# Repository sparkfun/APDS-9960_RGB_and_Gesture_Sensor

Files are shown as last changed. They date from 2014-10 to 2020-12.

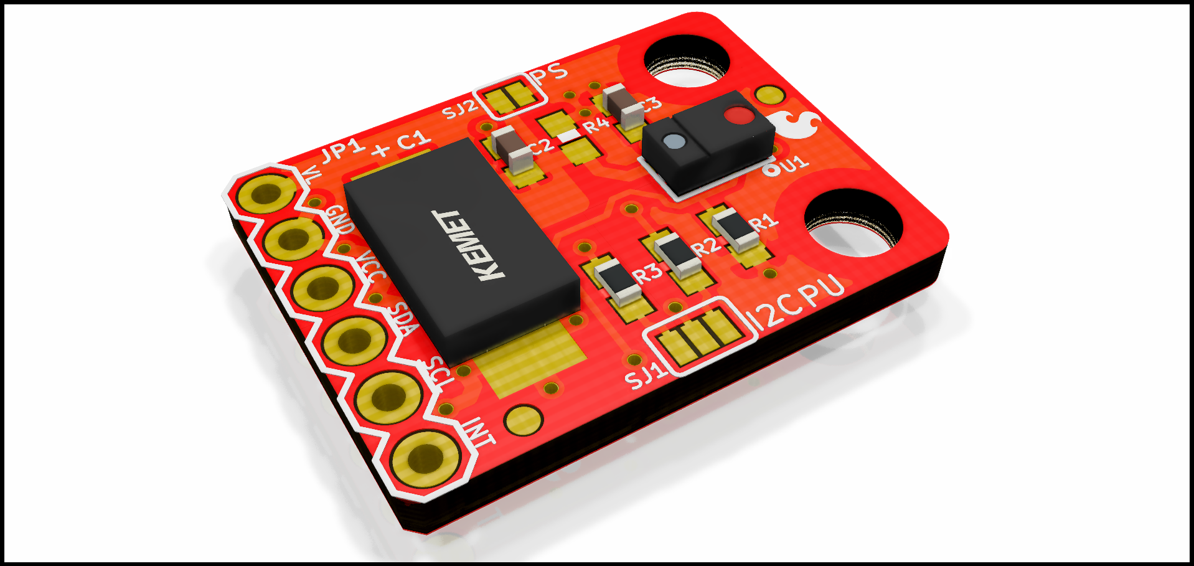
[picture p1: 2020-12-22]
Hardware/Kicad/RENDERS/SparkFun_APDS-9960_RGB_and_Gesture_Sensor_05.png

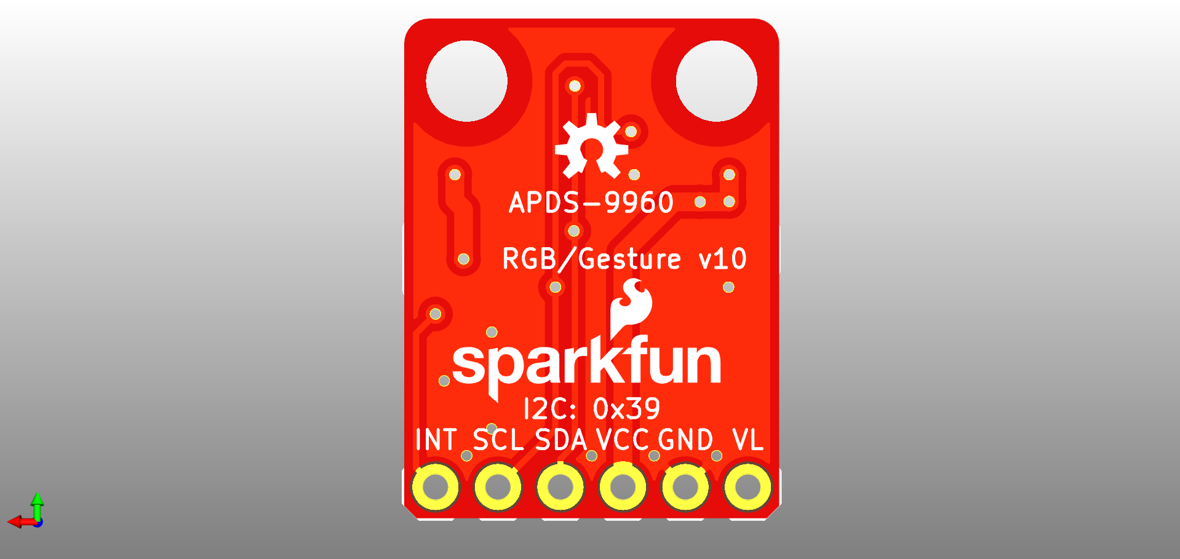
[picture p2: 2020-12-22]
Hardware/Kicad/RENDERS/SparkFun_APDS-9960_RGB_and_Gesture_Sensor_02.png

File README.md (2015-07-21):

SparkFun APDS-9960 RGB and Gesture Sensor
========================================

SparkFun APDS-9960 RGB and Gesture Sensor Breakout

[*SparkFun APDS-9960 Breakout Board (SEN-12787)*](https://www.sparkfun.com/products/12787)

This is the SparkFun RGB and Gesture Sensor, a small breakout board with a built in APDS-9960 sensor that offers ambient light and color measuring, proximity detection, and touchless gesture sensing.
With this RGB and Gesture Sensor you will be able to control a computer, microcontroller, robot, and more with a simple swipe of your hand! 

 Repository Contents
-------------------

* **/Hardware** - Eagle design files (.brd, .sch)
* **/Libraries** - Libraries for use with the SparkFun APDS9960 RGB and Gesture Sensor
* **/Production** - Production panel files (.brd)

Documentation
--------------
* **[Quickstart Guide](https://learn.sparkfun.com/tutorials/apds-9960-rgb-and-gesture-sensor-hookup-guide)** - Basic hookup guide for the sensor.
* **[Library/README](https://github.com/sparkfun/SparkFun_APDS-9960_Sensor_Arduino_Library/tree/V_1.4.1)** - Arduino library for the SparkFun_APDS9960 RGB and Gesture Sensor.
* **[SparkFun Fritzing repo](https://github.com/sparkfun/Fritzing_Parts)** - Fritzing diagrams for SparkFun products.
* **[SparkFun 3D Model repo](https://github.com/sparkfun/3D_Models)** - 3D models of SparkFun products. 

Product Versions
----------------
* **[SEN-12787](https://www.sparkfun.com/products/12787)** - APDS-9960 RGB and Gesture Sensor

Version History
---------------
* [V_H1.0_L1.4.2](https://github.com/sparkfun/APDS-9960_RGB_and_Gesture_Sensor/tree/V_H1.0_L1.4.2) - Fixing library name compiliation error. 
* [V_H1.0_L1.4.1](https://github.com/sparkfun/APDS-9960_RGB_and_Gesture_Sensor/tree/V_H1.0_L1.4.1) - Fixing minor typos in both library and hardware files.
* [V_1.1.1](https://github.com/sparkfun/APDS-9960_RGB_and_Gesture_Sensor/tree/V_1.1.1) - Updated to new tag syntax
* [V11](https://github.com/sparkfun/APDS-9960_RGB_and_Gesture_Sensor/tree/v11) - Updated to new library structure
* [v10](https://github.com/sparkfun/APDS-9960_RGB_and_Gesture_Sensor/tree/v10) - Release
* [v01](https://github.com/sparkfun/APDS-9960_RGB_and_Gesture_Sensor/tree/v01)

License Information
-------------------
This product is _**open source**_! 

The **hardware** is released under [Creative Commons ShareAlike 4.0 International](https://creativecommons.org/licenses/by-sa/4.0/).

The **code** is beerware; if you see me (or any other SparkFun employee) at the local, and you've found our code helpful, please buy us a round!

Please use, reuse, and modify these files as you see fit. Please maintain attribution to SparkFun Electronics and release anything derivative under the same license.

Distributed as-is; no warranty is given.

- Your friends at SparkFun.

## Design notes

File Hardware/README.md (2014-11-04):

# What Are these Files?

The .sch and .brd files hare are Eagle CAD schematic and PCB design files.

These files were created with Eagle 6.5.0, you'll need Eagle 6.5 or later to open them up. There is a free, lite, version of Eagle available from [cadsoftusa.com](cadsoftusa.com).

# License

This product is open source! These Eagle files are released under the Creative Commons Share-Alike Attribution license ([CC BY-SA 3.0](http://creativecommons.org/licenses/by-sa/3.0/us/)).

Please use, reuse, and modify these files as you see fit. Please maintain attribution and release anything derivative under the same license.

- Your friends at SparkFun.

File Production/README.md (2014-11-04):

These are the production files SparkFun uses for printing PCBs, as well as the Eagle files for our test beds.

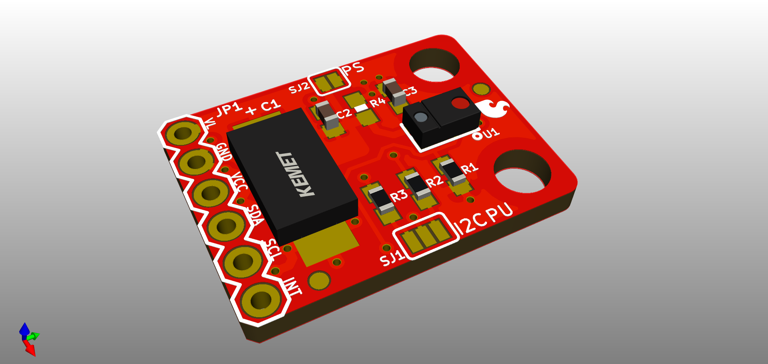
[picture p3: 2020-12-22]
Hardware/Kicad/RENDERS/SparkFun_APDS-9960_RGB_and_Gesture_Sensor_03.png

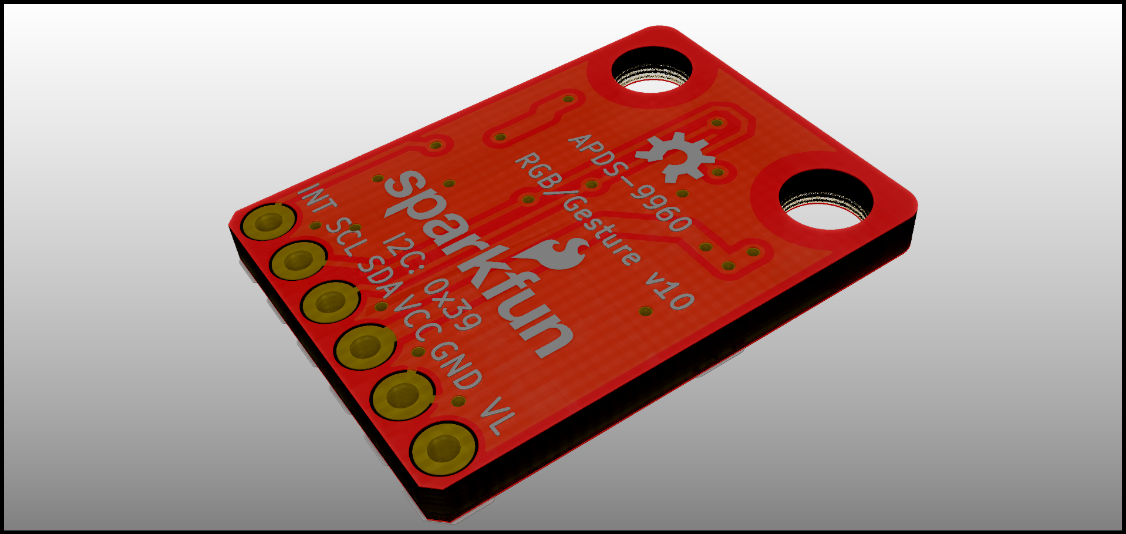
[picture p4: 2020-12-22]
Hardware/Kicad/RENDERS/SparkFun_APDS-9960_RGB_and_Gesture_Sensor_06.png

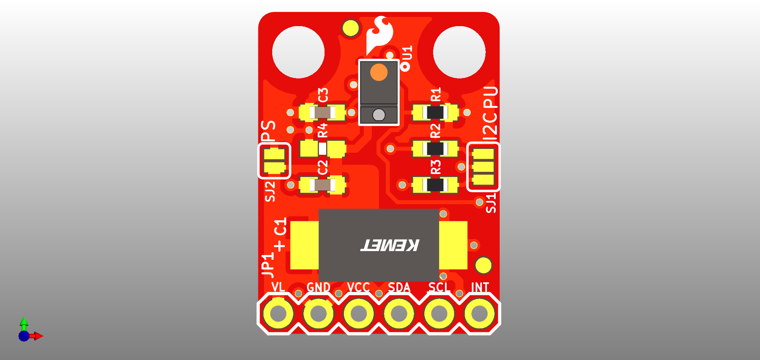
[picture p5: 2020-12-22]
Hardware/Kicad/RENDERS/SparkFun_APDS-9960_RGB_and_Gesture_Sensor_01.png

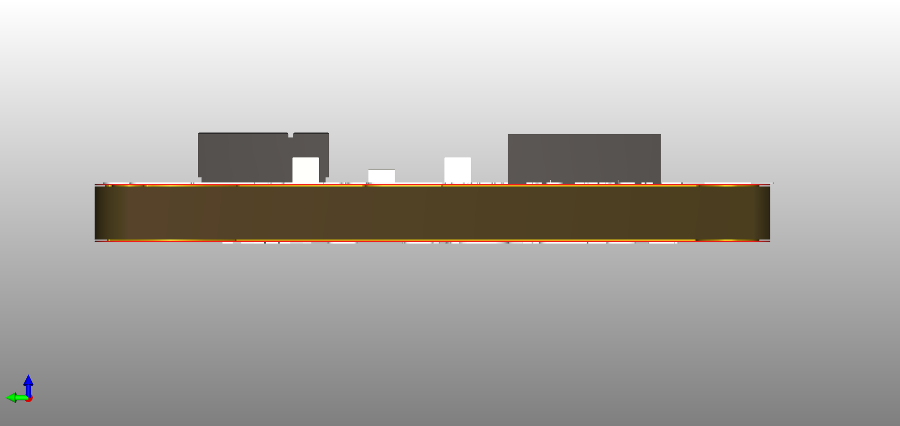
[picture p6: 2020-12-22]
Hardware/Kicad/RENDERS/SparkFun_APDS-9960_RGB_and_Gesture_Sensor_04.png

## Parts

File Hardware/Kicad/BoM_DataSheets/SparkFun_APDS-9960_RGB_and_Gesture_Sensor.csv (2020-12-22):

Id | Designator | Package | Quantity | Designation | Supplier and ref
1 | SJ2 | SJ_2S | 1 | SOLDERJUMPERNC
2 | U1 | APDS-9960 | 1 | APDS-9960
3 | C1 | c_2917 | 1 | 100uF
4 | C2,C3 | 0603-CAP | 2 | 1uF
5 | FID1,FID2 | FIDUCIAL-1X2 | 2 | FIDUCIAL1X2
6 | JP1 | 1X06 | 1 | M06SIP
7 | LOGO1 | SFE_LOGO_NAME_FLAME_.1 | 1 | SFE_LOGO_FLAME.1_INCH
8 | LOGO2 | OSHW-LOGO-S | 1 | OSHW-LOGOS
9 | R1 | 0603-RES | 1 | 10k
10 | R2,R3 | 0603 | 2 | 4.7k
11 | R4 | 0603-RES | 1 | DNP
12 | SJ1 | SJ_3_PASTE1&2&3 | 1 | SOLDERJUMPER_2WAYPASTE1&2&3
13 | STANDOFF1,STANDOFF2 | STAND-OFF | 2 | STAND-OFF
14 | U$1 | SFE_LOGO_FLAME_.1 | 1 | SFE_LOGO_NAME_FLAME.1_INCH

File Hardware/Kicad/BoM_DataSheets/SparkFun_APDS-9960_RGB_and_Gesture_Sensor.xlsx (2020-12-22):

Id | RefDes | Package | Quantity | Value
1 | C1 | c_2917 | 1 | 100uF
2 | C2, C3 | 0603-CAP | 2 | 1uF
3 | R1 | 0603-RES | 1 | 10k
4 | R2, R3 | 0603-CAP | 2 | 4.7k
5 | U1 | APDS-9960 | 1 | APDS-9960
 | KIT PARTS
6 | JP1 | 1X06 | 1 | M06SIP
 | DNP PARTS
7 | R4 | 0603-RES | 1 | DNP
 | VIRTUAL PARTS
8 | FID1, FID2 | FIDUCIAL-1X2 | 2 | FIDUCIAL1X2
9 | LOGO1 | SFE_LOGO_NAME_FLAME_.1 | 1 | SFE_LOGO_FLAME.1_INCH
10 | LOGO2 | OSHW-LOGO-S | 1 | OSHW-LOGOS
11 | SJ1 | SJ_3_PASTE1&2&3 | 1 | SOLDERJUMPER_2WAYPASTE1&2&3
12 | SJ2 | SJ_2S | 1 | SOLDERJUMPERNC
13 | STANDOFF1, STANDOFF2 | STAND-OFF | 2 | STAND-OFF
14 | U$1 | SFE_LOGO_FLAME_.1 | 1 | SFE_LOGO_NAME_FLAME.1_INCH

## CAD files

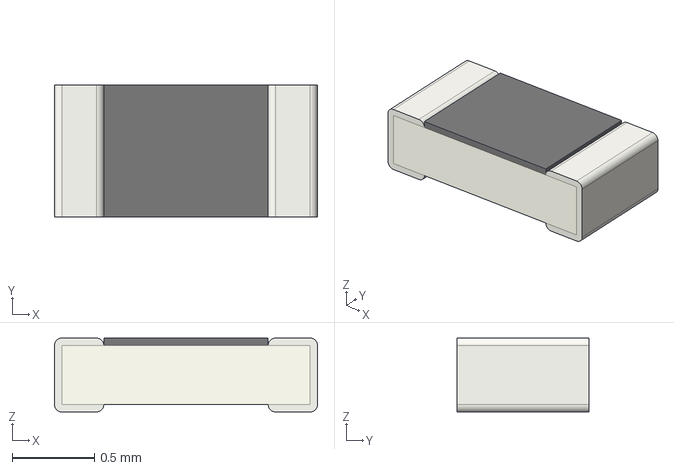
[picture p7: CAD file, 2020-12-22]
Hardware/Kicad/3D_models/R_0603_1608Metric.step
1.60 x 0.8 x 0.45 mm

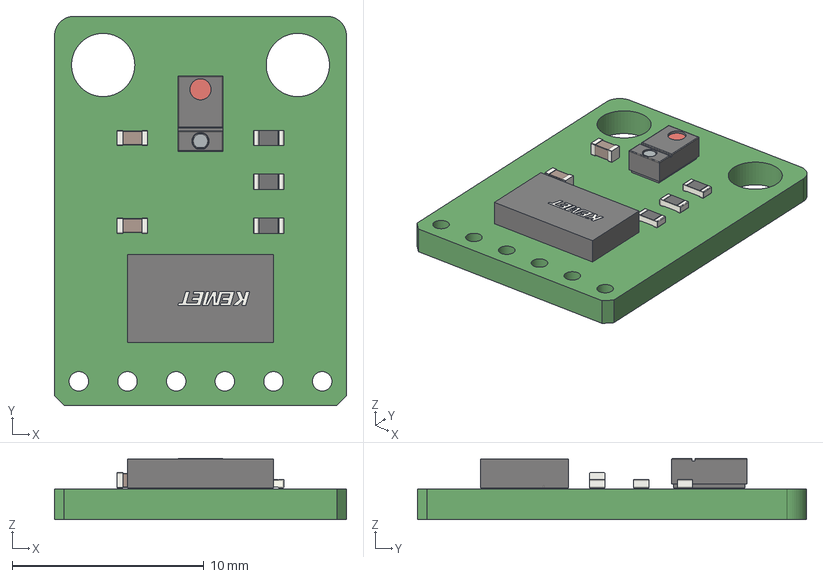
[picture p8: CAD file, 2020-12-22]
Hardware/Kicad/MECH/SparkFun_APDS-9960_RGB_and_Gesture_Sensor.step
15.2 x 20.3 x 3.20 mm

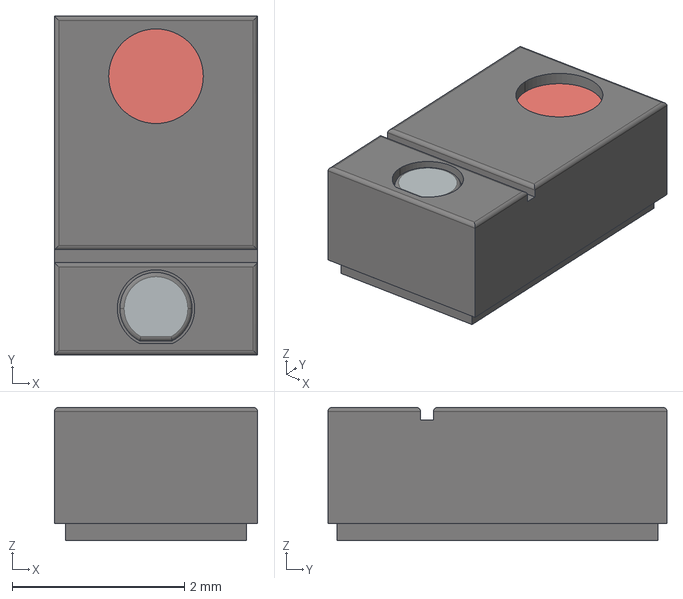
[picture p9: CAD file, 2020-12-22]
Hardware/Kicad/3D_models/APDS_9970_cp.step
2.36 x 3.94 x 1.55 mm

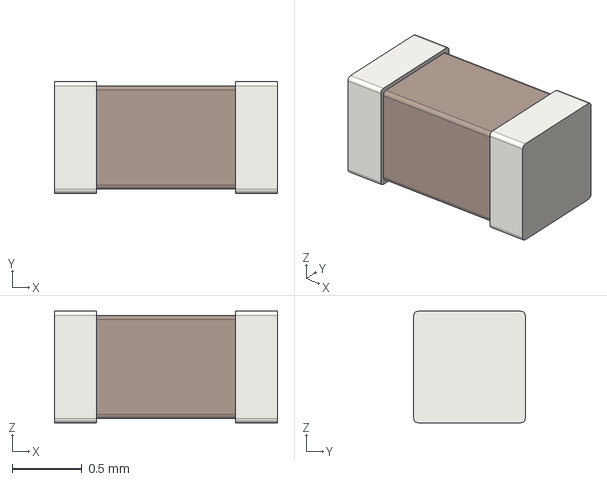
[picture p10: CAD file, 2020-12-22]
Hardware/Kicad/3D_models/C_0603_1608Metric.step
1.60 x 0.8 x 0.8 mm

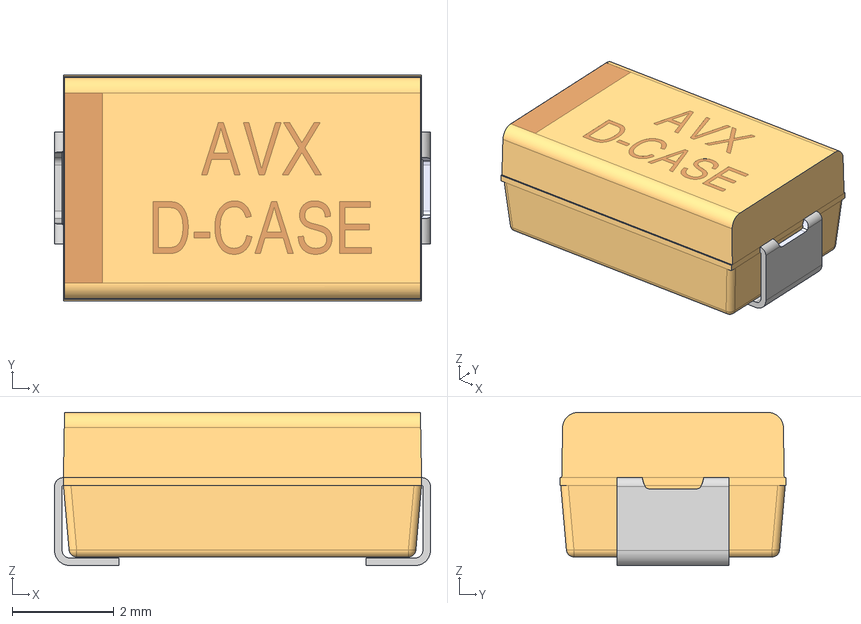
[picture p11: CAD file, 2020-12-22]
Hardware/Kicad/3D_models/cap_2917_7343M.step
7.40 x 4.45 x 3.01 mm

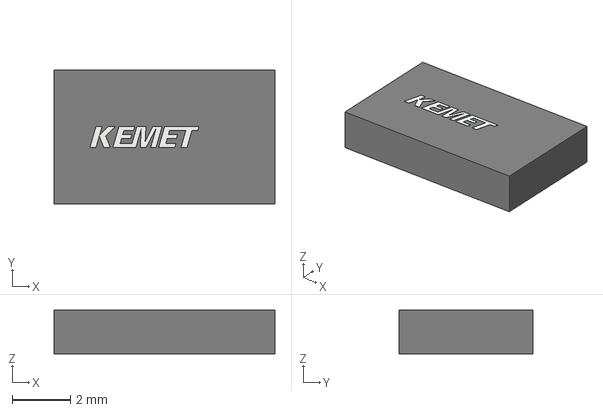
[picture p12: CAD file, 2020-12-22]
Hardware/Kicad/3D_models/cap_100uF_T523W107M016APE070.step
7.61 x 4.60 x 1.51 mm

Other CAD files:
Hardware/Kicad/3D_models/archive/cap_T523W107M016APE070.step
Hardware/Kicad/3D_models/archive/APDS-9960--3DModel-STEP-56544.step

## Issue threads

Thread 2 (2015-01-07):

Function "disableProximitySensor()" is unimplemented.

jmg5150, 2015-01-07:
bool disableProximitySensor() function is not implemented, calling it results in compile error. See line 342 of SparkFun_APDS9960.cpp.

The following function definition should give it the proper functionality.

/**
* @brief Ends the Proximity sensor on the APDS-9960
*
* @return True if sensor disabled correctly. False on error.
*/
bool SparkFun_APDS9960::disableProximitySensor()
{
	if (!setProximityIntEnable(0)) {
		return false;
	}
	if (!setMode(PROXIMITY, 0)) {
		return false;
	}

	return true;
}

ShawnHymel, 2015-01-14:
Copied to library and pushed back to GitHub. Thanks for the fix!

Closed 2015-01-14.

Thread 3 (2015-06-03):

Arduino uno with apds-9960

maosuyun2009, 2015-06-03:
Hi, When I connect APDS-9960 to my arduino uno and run GestureTest example, In init process, I always get 0x9F, when read value from APDS9960_ID register, what's wrong with it

ShawnHymel, 2015-06-03:
The ID should return 0xAB or 0x9C. How are you powering the APDS-9960 and which GPIO did you connect it to? The APDS-9960 is only rated for 3.3V.

maosuyun2009, 2015-06-03:
I connect A4 to SDA, A5 to SCL. VDD to 3.3v

ShawnHymel, 2015-06-03:
That sounds like it will work, considering the I2C lines are pulled up to 3.3V. There might be a new version of the chip that came out. I will pull a board from our production and see what ID reads for me. In the meantime,  you could comment out the lines in the init() function of the library that checks the ID to see if that still works for you.

maosuyun2009, 2015-06-05:
Hi, I comment out the lines in the init() function of the library, It's work perfect. I want to use APDS9960 in my linux system, where can i find apds9960 linux driver ?

ShawnHymel, 2015-06-08:
Great! I still have not had a chance to pull a new APDS9960 yet, but as soon as I do to verify the new address, I will update the library. Consider this the official workaround for now :)

There is no Linux driver that I am aware of. It would have to be ported to regular C and compiled for Linux. If you happen to find/make one, please let me know! Sadly, porting one isn't something I have time for right now :(

maosuyun2009, 2015-06-10:
Hi,
    I have ported this libray to my ar9331 linux board, Because ar9331 don't have i2c controller, so I use gpio to simulate i2c. But I can't read any register value except APDS9960_ID register(it's value is 0x9F). I have used my logic analyzer checked gpio output data, it's right. But Arduino uno can read register value correctly. The only differenc between Arduino and ar9331 is IO ouput voltage, ar9331 IO output voltage is 2.7v and arduino is 3.3v, Does it matter?

ShawnHymel, 2015-06-10:
According to the datasheet, the minimum I2C voltage for logic high is 1.26 V, so you should be fine. Remember that I2C lines are supposed to be open drain, so you might be affecting the lines with push-pull gpio. Can you configure them for open drain? Check out this post for using I2C from the AR9331: https://forum.openwrt.org/viewtopic.php?pid=166881#p166881

maosuyun2009, 2015-06-16:
Hi, I run ProximitySensor And GestureTest example in my arduino board, But I don't know why apds9960 continues send interrupt signal to arduino, Event though proximity is 0. Because of interrupt continues happened, when I hand over apds9960, I can't seen UP/DOWN or LEFT/RIGHT print

maosuyun2009, 2015-06-16:
Hi, I'm sorry bother you again. Ignore my previous question. I run ProximitySensor example code in my arduino uno and arduino pro board. arduino uno run perfectly, But arduino pro always read fifo data in while(1) loop. It seems APDS9960_GSTATUS register equals APDS9960_GVALID always true

ShawnHymel, 2015-06-16:
With the ProximitySensor example, the gesture recognition engine is never started (as with apds.enableGestureSensor(true) in the GestureTest example). I'm not sure what the behavior of GSTATUS and GVALID would be without setting the Gesture Enable bit. Can I ask why you are trying to read the gesture registers in the ProximitySensor example?

maosuyun2009, 2015-06-17:
Hi, I don't clearly explain my question. Exactly, When I run GestureTest example code in my Arduino Pro board, I have same problem like this https://forum.sparkfun.com/viewtopic.php?f=14&t=40026

ShawnHymel, 2015-06-17:
That's starting to sound like it might be a bad APDS-9960. Do you have a 3.3V Arduino or a logic level converter you could try? Otherwise, I recommend calling our customer service to see if you can get a replacement.

ShawnHymel, 2016-06-21:
Closing issue after no activity.

Closed 2016-06-21.

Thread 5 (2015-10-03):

Init not working

wscheper, 2015-10-03:
Everything is hooked up ok to my Arduino Uno, but then when the program is run it seems to freeze at the following statement (breakpoint B isn't executed). What could be the problem?

--from init method--
/* Read ID register and check against known values for APDS-9960 */
    if( !wireReadDataByte(APDS9960_ID, id) ) {
        Serial.println("breakpoint B");
        return false;
    }

Closed 2015-10-04.

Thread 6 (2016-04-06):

Gesture recognition fails if one diode pair is deactivated

HoLo85, 2016-04-06:
Hi,
there is a problem in the gestur recognition if you deactivate one pair of the photodiodes via the
"Gesture Configuration Three Register (0xAA)" register.
If one gesture dimension is switched off the complete recognition does not work anymore. It always returns NONE.
A quick fix seems to be by commenting out the lines 816-820 and changing the AND (&&) in line 803 and 836 into a OR (||).

ShawnHymel, 2016-06-21:
Thanks for bringing this up. If I get a chance, I will test this out on some hardware. I am currently swamped with other testing and tutorials at the moment.

MartyMacGyver, 2017-02-14:
Are those line refs correct for `Libraries/Arduino/src/SparkFun_APDS9960.cpp`? Because they don't seem to correspond to the current code, and it's unchanged from 2 years ago.

HoLo85, 2017-02-23:
Hi, sry for the late response. Looks like the code i had was a bit diffrent to the current code in the repo.
But the errors if described are still in there.
Comment this lines out (805-809):
`/* If one of the _first values is 0, then there is no good data */
        if( (u_first == 0) || (d_first == 0) || \
            (l_first == 0) || (r_first == 0) ) {
    
            return false;
}`
and change these:
`if( (gesture_data_.u_data[i] > GESTURE_THRESHOLD_OUT) &&
                (gesture_data_.d_data[i] > GESTURE_THRESHOLD_OUT) &&
                (gesture_data_.l_data[i] > GESTURE_THRESHOLD_OUT) &&
(gesture_data_.r_data[i] > GESTURE_THRESHOLD_OUT) ) {`
to
`if( (gesture_data_.u_data[i] > GESTURE_THRESHOLD_OUT) &&
                (gesture_data_.d_data[i] > GESTURE_THRESHOLD_OUT) ||
                (gesture_data_.l_data[i] > GESTURE_THRESHOLD_OUT) &&
                (gesture_data_.r_data[i] > GESTURE_THRESHOLD_OUT) ) {`
in line 791 and 823.

AndyEngland521, 2020-06-04:
Thanks for you help all! Adding these changes in v1.4.3

Closed 2020-06-04.

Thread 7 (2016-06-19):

Error with last commit in "GestureTest"

jcomega, 2016-06-19:
Hi,

The example "GestureTest" doesn't work (For hardware compatibility ) :
because interrupt management is not correct :

_attachInterrupt(0, interruptRoutine, FALLING);_
must be
_attachInterrupt(APDS9960_INT, interruptRoutine, FALLING);_

and loop() must be :
_void loop() {
  if( isr_flag == 1 ) {
    detachInterrupt(APDS9960_INT);
    handleGesture();
    isr_flag = 0;
    attachInterrupt(APDS9960_INT, interruptRoutine, FALLING);
  }
}_

ShawnHymel, 2016-06-21:
This does not work for the popular Arduino boards (Uno, Ethernet, Pro Mini). They have only interrupt numbers 0 and 1 available, so using an interrupt number of 2 would only work for the more powerful boards (e.g. Mega, Due, 32u4-based). For using a different hardware and interrupt number, please refer to https://www.arduino.cc/en/Reference/AttachInterrupt

Closed 2016-06-21.

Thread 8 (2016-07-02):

Color Sensing

vlast3k, 2016-07-02:
Can you please give me a hint, what the color sense (RGB feature) does?
I tried it but somehow the results aren't consistent
It always shows almost equal amounts of R G and B about 1/3 of the total ambient light
I tried to put the sensor in front of something Blue or Green or Red, but nothing changed too drasticaly.

Is this the feature or does it do something else ?

ShawnHymel, 2016-07-03:
It does sense amounts of red, green, and blue, but I find that it is not as accurate as some other dedicated RGB sensors. I recommend trying it with a colored light source, like a blue LED.

vlast3k, 2016-07-03:
ahh, i also suspected it would work better with light sources, thanks :)

Closed 2016-07-03.

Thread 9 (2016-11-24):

Why U,D,L,R registers sometimes give out of range values like 255?

hjjayakrishnan, 2016-11-24:
I've set GFIFOTH to trigger an interrupt when the fifolevel is greater than 8 datasets. In the interrupt handler I read the U,L,D,R registers until GFLVL is zero within a while loop and store the values into an array, so that I can compare the initial and final values to decode my gesture. But I have been getting values such as 255 in the registers. Following are the values I obtained while debugging, the first time it went to the interrupt handler when I waved my hand from left to right.

U	int[100]	[19, 35, 65, 125, 216, 255, 255, 255, 255, 255, 255, 255, 255, 244, 34, 12, 0, 0, 0, 0, 0, 0, 0, 0, 0, 0, 0, 0, 0, 0, 0, 0, 0, 0, 0, 0, 0, 0, 0, 0, 0, 0, 0, 0, 0, 0, 0, 0, 0, 0, 0, 0, 0, 0, 0, 0, 0, 0, 0, 0, 0, 0, 0, 0, 0, 0, 0, 0, 0, 0, 0, 0, 0, 0, 0, 0, 0, 0, 0, 0, 0, 0, 0, 0, 0, 0, 0, 0, 0, 0, 0, 0, ...]
D	int[100]	[20, 38, 70, 122, 197, 255, 255, 255, 255, 255, 255, 255, 255, 168, 27, 7, 0, 0, 0, 0, 0, 0, 0, 0, 0, 0, 0, 0, 0, 0, 0, 0, 0, 0, 0, 0, 0, 0, 0, 0, 0, 0, 0, 0, 0, 0, 0, 0, 0, 0, 0, 0, 0, 0, 0, 0, 0, 0, 0, 0, 0, 0, 0, 0, 0, 0, 0, 0, 0, 0, 0, 0, 0, 0, 0, 0, 0, 0, 0, 0, 0, 0, 0, 0, 0, 0, 0, 0, 0, 0, 0, 0, ...]
L	int[100]	[7, 9, 19, 34, 70, 138, 255, 255, 255, 255, 255, 255, 255, 255, 39, 13, 0, 0, 0, 0, 0, 0, 0, 0, 0, 0, 0, 0, 0, 0, 0, 0, 0, 0, 0, 0, 0, 0, 0, 0, 0, 0, 0, 0, 0, 0, 0, 0, 0, 0, 0, 0, 0, 0, 0, 0, 0, 0, 0, 0, 0, 0, 0, 0, 0, 0, 0, 0, 0, 0, 0, 0, 0, 0, 0, 0, 0, 0, 0, 0, 0, 0, 0, 0, 0, 0, 0, 0, 0, 0, 0, 0, 0, ...]
R	int[100]	[39, 63, 117, 200, 255, 255, 255, 255, 255, 255, 255, 255, 255, 53, 7, 7, 0, 0, 0, 0, 0, 0, 0, 0, 0, 0, 0, 0, 0, 0, 0, 0, 0, 0, 0, 0, 0, 0, 0, 0, 0, 0, 0, 0, 0, 0, 0, 0, 0, 0, 0, 0, 0, 0, 0, 0, 0, 0, 0, 0, 0, 0, 0, 0, 0, 0, 0, 0, 0, 0, 0, 0, 0, 0, 0, 0, 0, 0, 0, 0, 0, 0, 0, 0, 0, 0, 0, 0, 0, 0, 0, 0, 0, ...]

With values such as this I'm totally out of range and I can't properly decode the gestures. Any ideas why this is happening?

AndyEngland521, 2020-06-04:
Hmmm, can you please attach your code so I can have a look? Also, are you getting 255 during a gesture? What is occurring during data collection?

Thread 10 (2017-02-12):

Sensor will NOT work if logiclevel converter used

igittigitt, 2017-02-12:
Very strange, i bought such a sensor and also a bidirectional converter. But if i use this, the demo gesture sketch tells me that the sensor could not be initialized. I measured the voltages and can confirm the levelconverter works correct. On APDS-Side it uses 3.3V for SCA,SCL and also INT (i know it's not necessary, but so what the board has 4 converters on it) and on the Arduino Uno side 5V for logic level.

Now, after playing around for a while a decided to test the signals (! NOT Vcc, for shure!) without the converter, hence i know it possible kill my sensor... But for some reason it then works! I'm confused. Checked everything double, test again, but it is that way: using a converter -> no chance. without it -> all right.

Can somebody clearify this? The sensor is the simple one, without any extra logic on board. Just the cap and the pullups.

ShawnHymel, 2017-02-13:
What kind of logic level converter are you using? I2C has problems with them sometimes.

Also, because I2C is open drain, you can just connect VCC to 3.3V from the Arduino and connect SDA and SCL to your I2C pins. SCL and SDA will be driven LOW but never HIGH (open drain). The 4.7k pullups on the APDS-9960 breakout will ensure that SCL and SDA will be nominally pulled to 3.3V (not 5), which acts as a sort of level converter.

You likely don't need a level converter on INT, as it's pulled high to 3.3V as well, which is good enough for logic level high for your 5V TTL on your Arduino for GPIO input.

igittigitt, 2017-02-21:
Thanks a lot. This all makes sense to mee! But i think one should strictly void to use internal pullup of inputs (activated by the "_PULLUP" macro) and only use those external pullup resistors.
It not really explains why using an, even unnecessary, levelshift will break communication totally... i'm using this kind of convert: http://i.ebayimg.com/images/g/wK0AAOSw8aNXGkGD/s-l1600.jpg

ShawnHymel, 2017-02-21:
That's a similar converter to the one SparkFun sells, so it's good for general I/O, SPI, and UART (just not at super high speeds). And yes, with I2C, external pullups are the way to go. Did everything work out for you?

RupinC, 2018-04-04:
I am having a similar problem. Did this scheme of wiring work?

loricrotser, 2019-11-01:
I am closing this issue since it hasn't been touched in over a year. If you need further technical assistance, feel free to visit the [SparkFun forums](https://forum.sparkfun.com/index.php) and we'll see what we can do to help you out. Thank you!

Closed 2019-11-01.

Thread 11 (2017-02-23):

Sensor not working with a glass cover above it

nikilrao, 2017-02-23:
I'm using a glass cover (90% IR transmittance) on top of the sensor. Because of this there's always data in the FIFO and it's stuck in this if statement -

```
if( (gstatus & APDS9960_GVALID) == APDS9960_GVALID ) {
.......}
```

From what I understood, the FIFO becomes empty after the gesture is completed and then it enters this else statement -

```
else {

            /* Determine best guessed gesture and clean up */
            delay(FIFO_PAUSE_TIME);
            decodeGesture();
            motion = gesture_motion_;
#if DEBUG
            Serial.print("END: ");
            Serial.println(gesture_motion_);
#endif
            resetGestureParameters();
            return motion;
        }
```

and the final gesture is determined. So the gesture is not being detected because it never enters this else statement. How can I solve this problem? Thanks!

HoLo85, 2017-02-24:
How big is the distance between the cover glass and your sensor?
If its to big the sensor will think there is always something above it.

nikilrao, 2017-02-24:
I've tried almost all distances ranging from right on top of the sensor to a few mm above it.

HoLo85, 2017-02-27:
My problem is that i dont have access to the sensor anymore, so im maybe not a big help.
@nikilrao have you tried putting a foam around the sensor to keep light out from the environment?
That helped me when i worked with the sensor. I also removed the capacitor and put it on the backside of the board, to be able to glue the sensor directly to the cover i used.

lillyagar, 2018-09-07:
Hello @HoLo85 I know its a year later! lol but just wanted to know how foam work for you? I am trying to do the same thing but I'm not having any luck. If possible, could you attach a photo of it, to see an example? Thank you! (:

HoLo85, 2018-12-23:
Hi, sry for the (really) late answer. I stopped working on the project over a year ago and i don't have any access to it anymore. In the end a thin layer of foam around the sensor helped, but you should keep the gap between the sensor and glas below 1 mm.

loricrotser, 2019-10-30:
Hey all, since this hasn't been touched in almost a year, I'm going to close the issue.

If you need further technical assistance, head over to our [forums](https://forum.sparkfun.com/index.php) and we'll see what we can do to help you out. Thank you!

Closed 2019-10-30.

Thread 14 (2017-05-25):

Arduino uno with apds-9960

lollo03, 2017-05-25:
I connect vcc to 3.3V, SDA to A4, SCL to A5. BUt when i try to run proximitysensor.ino in my serial monitor i have only this:

 SparkFun APDS-9960 - ProximitySensor

and nothing else... how i can fix it ??

loricrotser, 2019-10-30:
Hello! Apologies for the delay in response - I have just been assigned this. :D

I snagged an old Uno from our tech support guys and I was able to hook this up and get the ProximitySensor sketch running with no problem. Since the github issues are used for bugs and pull requests related to the libraries or pcbs, you may want to try the [forums](https://forum.sparkfun.com/index.php) to get more technical information, if you still need it. Thank you!

Closed 2019-10-30.

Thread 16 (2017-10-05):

Sensor code running but sensor not detecting gesture

devduttamukherjee1, 2017-10-05:
I have downloaded the files from, here, the code seems to be running, on uploading the sketch to the arduino the code shows running but the gesture sensor is not detecting any gesture, on the other hand the proximity detection and ambiance light color detection works perfectly fine. Kindly help!

magora-obukhov, 2019-06-24:
Same issue

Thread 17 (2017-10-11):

Gesture and proximity don't work well together

SelaO, 2017-10-11:
I have this in my setup():

 ```
  // Initialize interrupt service routine
  attachInterrupt(0, interruptRoutine, FALLING);

  // Initialize APDS-9960 (configure I2C and initial values)
  if ( apds.init() ) {
    Serial.println(F("APDS-9960 initialization complete"));
  } else {
    Serial.println(F("Something went wrong during APDS-9960 init!"));
  }

  // Adjust the Proximity sensor gain
  if ( !apds.setProximityGain(PGAIN_2X) ) {
    Serial.println(F("Something went wrong trying to set PGAIN"));
  }

  // Start running the APDS-9960 proximity sensor (no interrupts)
  if ( apds.enableProximitySensor(false) ) {
    Serial.println(F("Proximity sensor is now running"));
  } else {
    Serial.println(F("Something went wrong during sensor init!"));
  }

    // Start running the APDS-9960 gesture sensor engine
  if ( apds.enableGestureSensor(true) ) {
    Serial.println(F("Gesture sensor is now running"));
  } else {
    Serial.println(F("Something went wrong during gesture sensor init!"));
  }
```

And the values from the proximity are either 41 or below 10, but if I remove the `if ( apds.enableGestureSensor(true) ) {...` then it works well with values between 0 and 255.

How can I make both of those features to work well together?

ShawnHymel, 2017-10-11:
It's been a while since I've used the APDS-9960, but I think I've had issues with these two working together in the past. Because the GenstureSensor part of the library relies on the proximity sensor (it's what triggers the gesture engine to start recording events), getting them to work together at the same time might be difficult. Is there a way where you can have only one operating at a time (e.g. proximity on, when it detects a certain event, turn the gesture engine on and disable the proximity portion)?

SelaO, 2017-10-11:
I need them to work together...

loricrotser, 2019-10-31:
After reading the [datasheet](https://cdn.sparkfun.com/datasheets/Sensors/Proximity/apds9960.pdf), it appears that control of that drive pin is shared between proximity and gesture functionality, so having them work together at the same time is going to be tricky. You'd have to boot multiple engines at once, do your reading, and then get the data from both. I haven't tried it, but you might try the [SparkFun forums](https://forum.sparkfun.com/index.php) to see if someone else has done it. Hope that is helpful!

Closed 2019-10-31.

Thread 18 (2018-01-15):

Gesture Sensor Interrupt Frozen on 8266?

beachmiles, 2018-01-15:
On a wemos mini I think I am getting INT lockups for the gesture sensor.
I am still getting brightness readings over i2c ok.

It seems like the swipe works good for the first 15-30 swipes but then will stop working, or if I leave it running overnight in the morning the gesture sensor no longer activates.

I put a 2 second timeout in the apds.readGesture() function to try an avoid lockups if an object gets placed in front of the sensor but that didnt help.

AndyEngland521, 2020-06-04:
Can you please provide your code?

Closed 2020-06-04.

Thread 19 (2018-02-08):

Multiple troubles with the readings

albydnc, 2018-02-08:
I have bought an apds9960 sensor and attached it to my MKR1000 board. The library is saying initialization complete but then proximity readings are always 0. the Color Sensor and Ambient light examples are working but the readings of green and blue are wrong (-1, 0). What could be the problem? thanks.
I was thinking is a problem with the IR led.

loricrotser, 2019-10-31:
Hi! Apologies for the long delay in response, I was just assigned this.

I don't have a 1000 in house, but I did just test it with the MKR Vidor 4000. I didn't see any issues - all my proximity readings came through as expected. Maybe try double checking the pin connections?

If you still need help, I'd recommend hopping onto the [SparkFun forums](https://forum.sparkfun.com/index.php) to see if tech support can dig in a little further. The issues here are more for code and library bugs, hence the long reply time.

Hope this is helpful!

Closed 2019-10-31.

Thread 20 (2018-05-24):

Gesture Sensor example not working with Attiny84(1)

Michael-Bell, 2018-05-24:
Tested with v1.1.5 of https://github.com/SpenceKonde/ATTinyCore

Arduino Uno works with level converters
Attiny85 works when using 3.3v and 5v w/ level converter.

Attiny84 and Attiny841 do not work at 3.3v or at 5v w/ level converter.

AndyEngland521, 2020-06-04:
@Michael-Bell Hmmm, I'm vaguely aware of an issue occurring when you have both Dave Mellis and Spence Konde's ATTiny core's installed, could you uninstall the Dave Mellis core?

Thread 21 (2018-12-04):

ADSP9960 Interrupt is issuing interrupt. Weired isn't it?

laxmimerit, 2018-12-04:
Hi,
I am facing a weird kind of problem. Int pin is not issuing interrupt some times. I have tried with almost 5 to 6 modules. what could be cause of error?
Here is snippet of code

```
// Initialize APDS-9960 (configure I2C and initial values)
    if (apds.init()) {
        printf("APDS-9960 initialization complete\n");
    } else {
        printf("Something went wrong during APDS-9960 init!\n");
    }

// Adjust the Proximity sensor gain
    if (!apds.setProximityGain(PGAIN_8X)) {
        printf("Something went wrong trying to set PGAIN\n");
    }

// Set proximity interrupt thresholds
    if (!apds.setProximityIntLowThreshold(PROX_INT_LOW)) {
        printf("Error writing low threshold\n");
    }
    if (!apds.setProximityIntHighThreshold(PROX_INT_HIGH)) {
        printf("Error writing high threshold\n");
    }

// Start running the APDS-9960 proximity sensor (with interrupts)
    if (apds.enableProximitySensor(true)) {
        printf("Proximity sensor is now running in Interrupt mode\n");
    } else {
        printf("Something went wrong during sensor init!\n");
    }

while (1) {   // Read the proximity value
        if (!apds.readProximity(proximity_data)) {
            printf("Error reading proximity value\n");
        } else {
            printf("Proximity: %u\n", proximity_data);
        }
        if(!apds.clearProximityInt()){
            printf("Error in clearing Interrupt \n");
        }
    }
```

loricrotser, 2019-10-30:
I don't see where you've attached an interrupt to pin 2 - maybe I just don't have enough of your code? That would be a good place to start though. :D

If you still need technical help, I'd recommend the [forums](https://forum.sparkfun.com/index.php). The github issues are used primarily for bugs and pull requests related to the libraries or pcbs. The tech support guys can dig in a bit more with your individual code.

Thank you!

Closed 2019-10-30.

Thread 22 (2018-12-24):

Copy a color to RGB LED (KY09 RGB LED SMD Tri Color Module) using APDS9960 RGB color sensor

armak1983-2018, 2018-12-24:
i am using the following sketch to copy color to RGB LED using APDS9960 RGB sensor.

the sketch was uploaded successfully, but the LED is not working when color is put in front of the sensor!

#include <Wire.h>
#include "Adafruit_APDS9960.h"
Adafruit_APDS9960 apds;

#define redpin 3
#define greenpin 5
#define bluepin 6

#define commonAnode false

byte gammatable[256];

void setup() {
  Serial.begin(9600);
  Serial.println("Color View Test!");

  if (apds.begin()) {
    Serial.println("Found sensor");
  } else {
    Serial.println("No TCS34725 found ... check your connections");
    while (1); // halt!
  }

  pinMode(redpin, OUTPUT);
  pinMode(greenpin, OUTPUT);
  pinMode(bluepin, OUTPUT);

  for (int i=0; i<256; i++) {
    float x = i;
    x /= 255;
    x = pow(x, 2.5);
    x *= 255;

    if (commonAnode) {
      gammatable[i] = 255 - x;
    } else {
      gammatable[i] = x;
    }
    //Serial.println(gammatable[i]);
  }
}

void loop() {
  //create some variables to store the color data in
  uint16_t clear, red, green, blue;

  //wait for color data to be ready
  while(!apds.colorDataReady()){
    delay(5);
  }

  //get the data and print the different channels
  apds.getColorData(&red, &green, &blue, &clear);
  Serial.print("red: ");
  Serial.print(red);

  Serial.print(" green: ");
  Serial.print(green);

  Serial.print(" blue: ");
  Serial.print(blue);

  Serial.print(" clear: ");
  Serial.println(clear);
  Serial.println();

  delay(1000);
   // Figure out some basic hex code for visualization
  uint32_t sum = clear;
  float r, g, b;
  r = red; r /= sum;
  g = green; g /= sum;
  b = blue; b /= sum;
  red *= 256; green *= 256; blue *= 256;
  Serial.print("\t");
  Serial.print((int)r, HEX); Serial.print((int)g, HEX); Serial.print((int)b, HEX);
  Serial.println();

  analogWrite(redpin, gammatable[(int)r]);
  analogWrite(greenpin, gammatable[(int)g]);
  analogWrite(bluepin, gammatable[(int)b]);
}

nseidle, 2019-01-02:
Hi - Looks like you're using the adafruit library? Sorry, but we can't help much. You should give the [SparkFun library](https://github.com/sparkfun/SparkFun_APDS-9960_Sensor_Arduino_Library/blob/master/examples/ColorSensor/ColorSensor.ino) a try.

Closed 2019-01-02.

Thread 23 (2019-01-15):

This statement is always FALSE

laxmimerit, 2019-01-15:
https://github.com/sparkfun/APDS-9960_RGB_and_Gesture_Sensor/blob/a2550e1c07e783cc539a26651d478ab0aa7acf35/Libraries/Arduino/APDS-9960_RGB_and_Gesture_Sensor_Arduino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

this statement is always false since uint8_t cannot be negative in any circumstances.

loricrotser, 2019-10-30:
Hi! It looks like bytes_read is simply a counter, I'm not sure why it was made a uint. I'll fix it shortly. Thanks for the heads up!

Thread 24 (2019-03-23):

Usage of Wire library.

Koepel, 2019-03-23:
In the file "APDS-9960_RGB_and_Gesture_Sensor/Libraries/Arduino/APDS-9960_RGB_and_Gesture_Sensor_Arduino_Library/src/SparkFun_APDS9960.cpp", the function "wireWriteDataBlock()" is not used, but it contains a bug.

The sequence should be: beginTransmission - write - write -write - endTransmission
However, instead of writing data, a Wire.beginTransmission() is called (multiple) times.
At the moment it is at line [2152](https://github.com/sparkfun/APDS-9960_RGB_and_Gesture_Sensor/blob/master/Libraries/Arduino/APDS-9960_RGB_and_Gesture_Sensor_Arduino_Library/src/SparkFun_APDS9960.cpp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).

AndyEngland521, 2020-06-04:
Good catch, fixed in v1.4.3

Closed 2020-06-04.

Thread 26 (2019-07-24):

setProximityGain has no effect in ProximitySensor.ino example

wollewald, 2019-07-24:
Changing the PGAIN value in line 61 in the example ProximitySensor.ino has no effect. This is because the enableProximitySensor function (line 66) sets the DEFAULT_PGAIN. Therefore PGAIN changes through setProximityGain needs to be done after enabling the sensor.

loricrotser, 2019-10-29:
Hi! I'm just now seeing this, but you, sir, are correct. I'll get this fixed here soon. Thanks for the heads up!

loricrotser, 2019-10-30:
Fixed. Thanks again!

[Commit 258bea2
](https://github.com/sparkfun/APDS-9960_RGB_and_Gesture_Sensor/commit/258bea2dadc573706ab1e6176f1dea1623e4cffb)

Closed 2019-10-30.

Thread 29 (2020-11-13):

Esp8266 GestureTest

Oopas, 2020-11-13:
I tried to use the library on esp8266, but it was constantly rebooting....

Oopas, 2020-11-13:
Here's some information

--------------------------------
SparkFun APDS-9960 - GestureTest
--------------------------------
ISR not in IRAM!

User exception (panic/abort/assert)
--------------- CUT HERE FOR EXCEPTION DECODER ---------------

Abort called

>>>stack>>>

ctx: cont
sp: 3ffffef0 end: 3fffffc0 offset: 0000
3ffffef0:  2d2d2d2d 2d2d2d2d 2d2d2d2d 2d2d2d2d
3fffff00:  000000fe 00000000 00000000 00000000
3fffff10:  00000000 00000000 00000000 00ff0000
3fffff20:  5ffffe00 5ffffe00 000a0d00 00000000
3fffff30:  00000002 00000000 3ffee4f4 40202cb2
3fffff40:  4010072e 402043d5 ffffffff 40202cc4
3fffff50:  40201f9c 3ffee4f4 3ffee4f4 4020391d
3fffff60:  00000000 3ffee4f4 3ffe8631 402021a1
3fffff70:  3fffdad0 00000020 3ffee4f4 3ffee55c
3fffff80:  3fffdad0 00000000 3ffee4f4 402039cc
3fffff90:  3fffdad0 00000000 3ffee4f4 4020109c
3fffffa0:  feefeffe 00000000 3ffee51c 402028c0
3fffffb0:  feefeffe feefeffe 3ffe84e8 40101029
<<<stack<<<

Pezhvak, 2020-11-14:
+1

jschoch, 2021-03-16:
you may need to add ICACHE_RAM_ATTR to the isr function...

```
void ICACHE_RAM_ATTR interruptRoutine() {
  isr_flag = 1;
}
```

Bob0707, 2023-09-09:
73 |   attachInterrupt(0, interruptRoutine, FALLING);
95 |     attachInterrupt(0, interruptRoutine, FALLING);
Compilation error: 'interruptRoutine' was not declared in this scope

That is what i get after add ICACHE_RAM_ATTR to the ISR function, can anyone help?

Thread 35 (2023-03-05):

Update the verision in the Arduino Library Manager

codemee, 2023-03-05:
The version now in the Arduino Library Manager is 1.4.2 of the [SparkFun APDS9960 RGB and Gesture Sensor Arduino Library](https://github.com/sparkfun/SparkFun_APDS-9960_Sensor_Arduino_Library) repo. It cannot accept the device id of 0xA8. Would you please update the verion in the Arduino Library Manager? Thanks.

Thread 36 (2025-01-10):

APDS 9960 clone initialization problem

Queequack, 2025-01-10:
First of all: The (cloned) sensor works perfectly. My question mainly relates to a method for implementing my workaround generically and reliably.

With some clones, `apds.init()` (with `SparkFun_APDS9960 apds = SparkFun_APDS9960();`) can return false. The initialization therefore fails. A clever guy has found a [solution](https://wiki.robotika.sk/robowiki/index.php?title=Getting_a_clone_of_APDS-9960_to_work) for this: In `SparkFun_APDS9960.h`, change the line `#define APDS9960_ID_1` from `0xAB` to `0xA8` (not b but 8 [eight]).

As I work with several boards and environments, I am now trying to overwrite the library value in platformio.ini with `build_flags = -D APDS9960_ID_1=0xA8`. This also works... Halfway there. Without changing the value in the library itself (separately for each environment), my main problem is: I am processing the status of the sensor. Because then, the initialization (`init()`) returns always false and the sensor is classified as non-functional in my application.
Related and expected warning during the build process:
```
In file included from include/APDS9960.h:5,
                 from src/main.cpp:32:
.pio/libdeps/RoomPanel_esp32-s3-devkitc-1-n16r8v_OTA/SparkFun APDS9960 RGB and Gesture Sensor/src/SparkFun_APDS9960.h:34: warning: "APDS9960_ID_1" redefined
#define APDS9960_ID_1           0xAB
```
I'm not sure if the warning means that
a) the library value is being overwritten or
b) the build_flag value in my config is being overwritten
Apparently overwriting the library value does not work properly.

Two scenarios with changes in the two files:

**First and it works**
`platformio.ini`: No content that affects the sensor (no build flag)
`SparkFun_APDS9960.h`: `#define APDS9960_ID_1 0xAB` CHANGED from 0xAB to 0xA8.
The sensor and the `init()` work error-free without exception.

But I would like to implement this variant:
**Second and that does not work reliably**
`platformio.ini`: `build_flags = -D APDS9960_ID_1=0xA8`
`SparkFun_APDS9960.h`: Not changed (still `#define APDS9960_ID_1 0xAB`)
The following initializations work (_setProximityIntLowThreshold(...), setProximityIntHighThreshold(...), enableProximitySensor(...), setProximityGain(...), enableLightSensor(...)_). However, the behavior is not reproducible. I noticed differences when I flashed via different environments (e.g. via USB or via OTA):
_Case 1, `init()` returns false, but sensor returns correct values_:
- Light sensor delivers correct values (e.g. around 1000 in daylight, somewhat in the shade)
- Proximity sensor and Itnerrupt work as expected

_Case 2 `init()` returns false, sensor returns incorrect values_:
- Light sensor provides correct values between 10 and 20 (instead of around 1000 in comparison)
- Proximity sensor repeatedly triggers at values between approx. 3 and 6

Regards

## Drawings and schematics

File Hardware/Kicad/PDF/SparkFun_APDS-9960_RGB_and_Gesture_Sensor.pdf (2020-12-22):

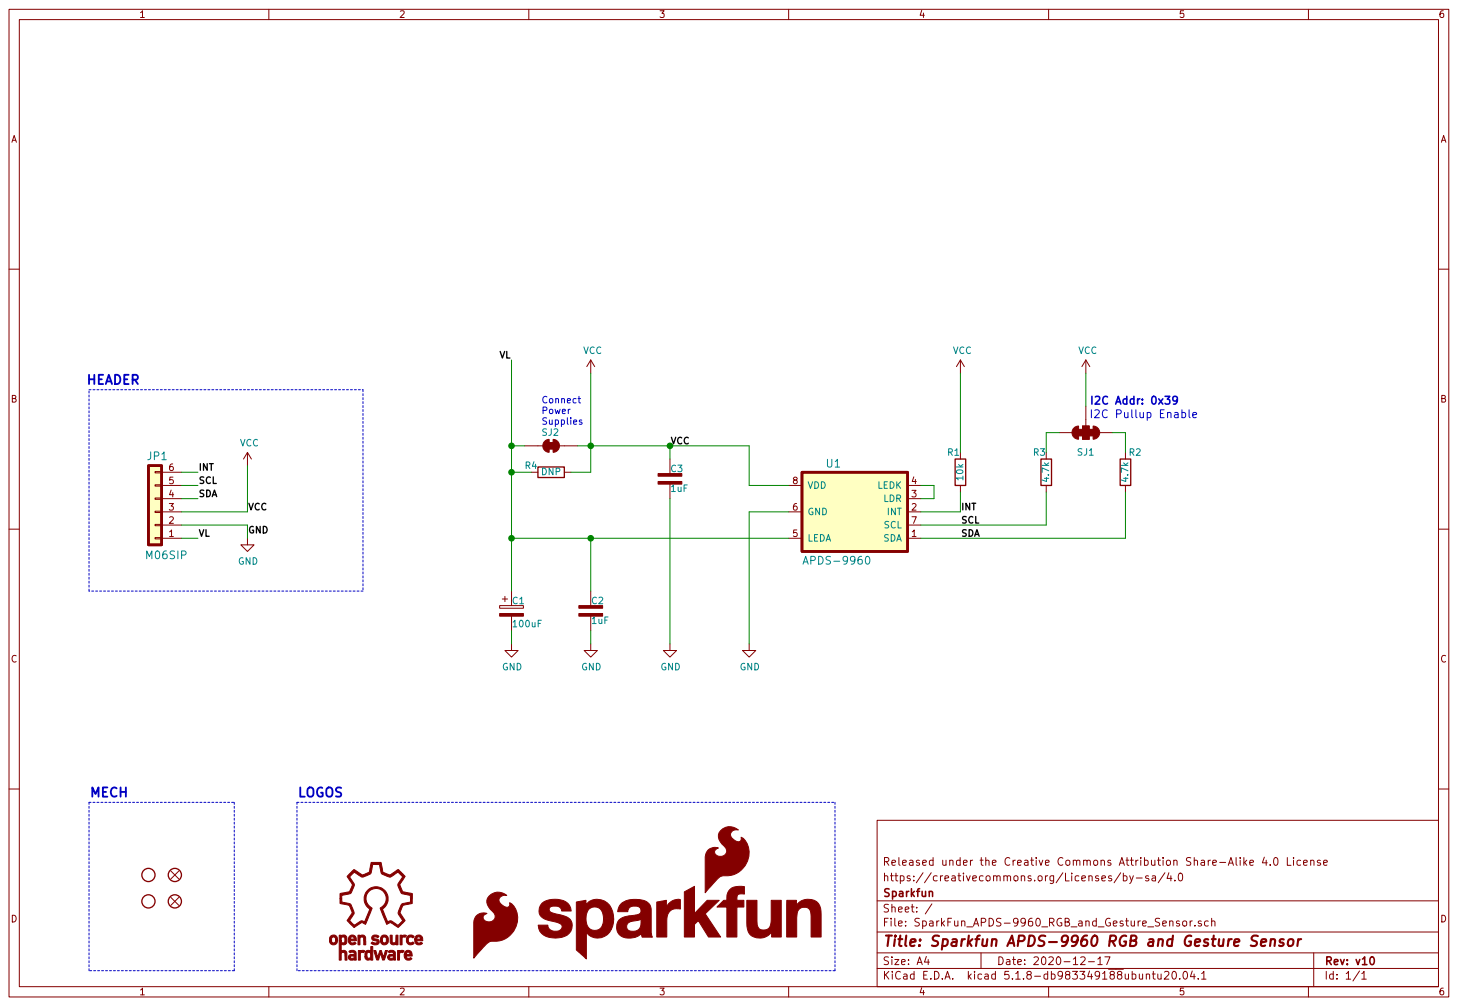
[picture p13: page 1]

File: SparkFun_APDS-9960_RGB_and_Gesture_Sensor.sch Sheet: / Sparkfun

Id: 1/1 Title: Sparkfun APDS-9960 RGB and Gesture Sensor

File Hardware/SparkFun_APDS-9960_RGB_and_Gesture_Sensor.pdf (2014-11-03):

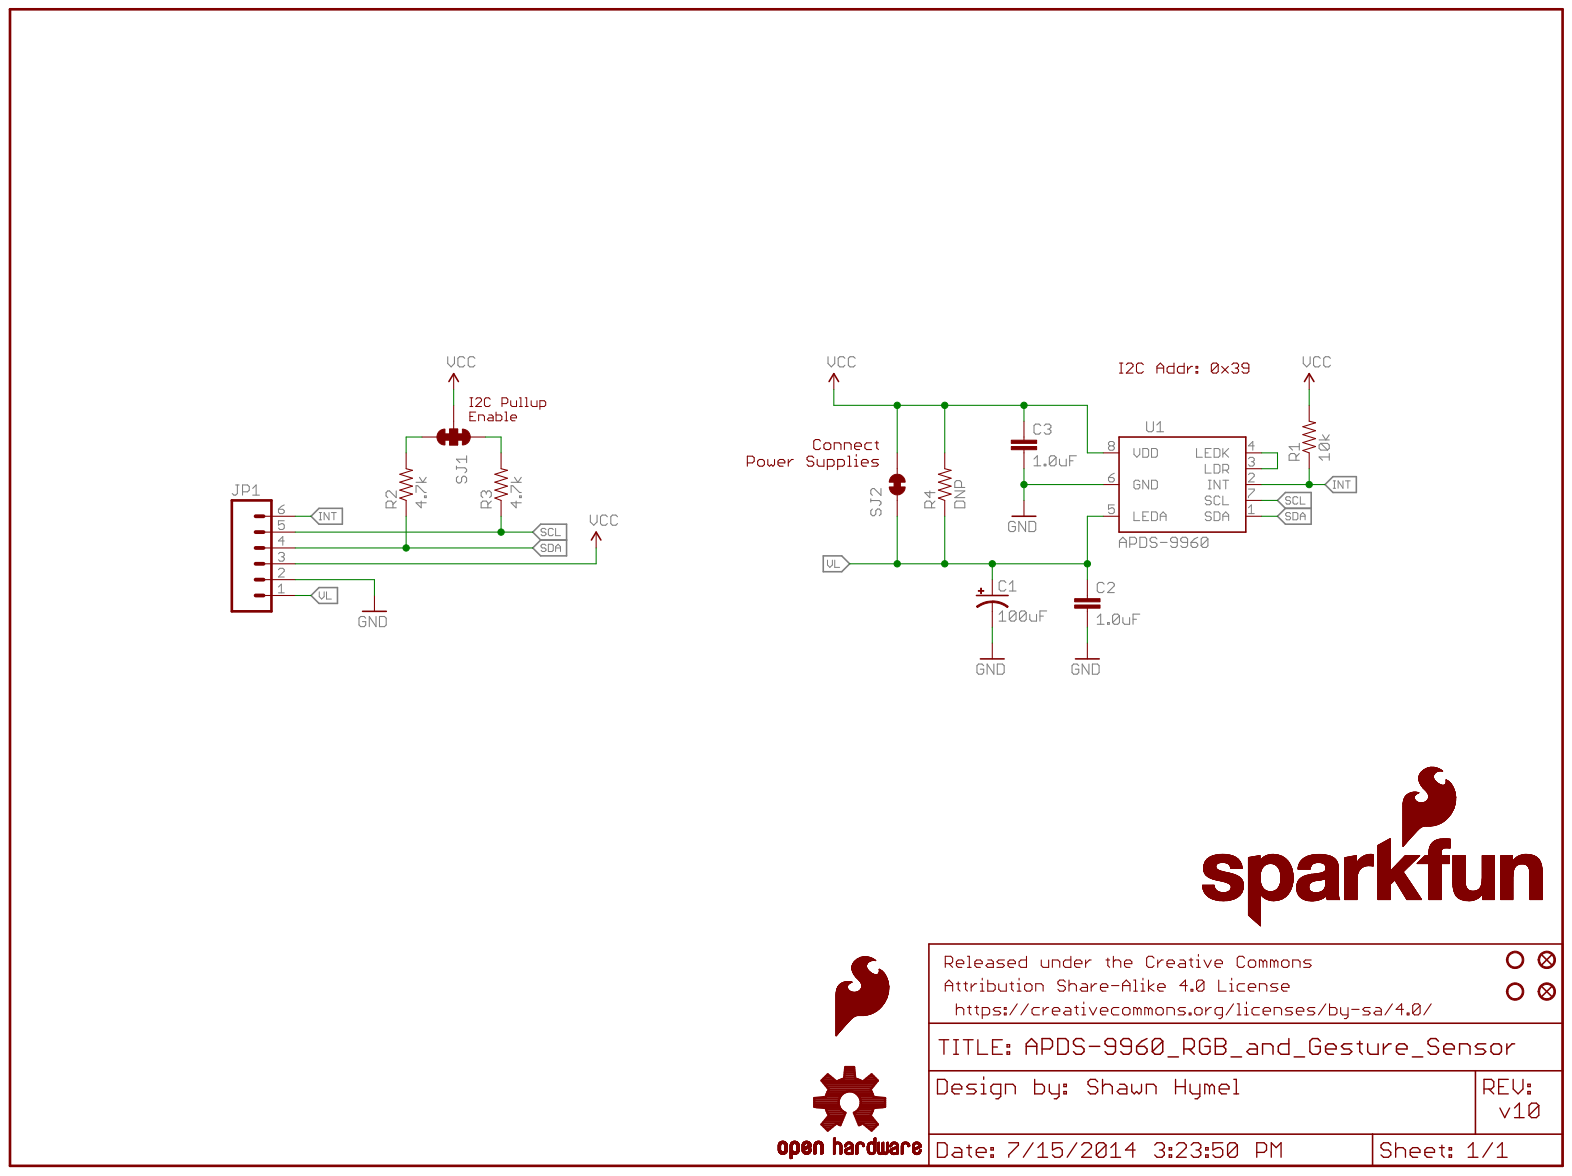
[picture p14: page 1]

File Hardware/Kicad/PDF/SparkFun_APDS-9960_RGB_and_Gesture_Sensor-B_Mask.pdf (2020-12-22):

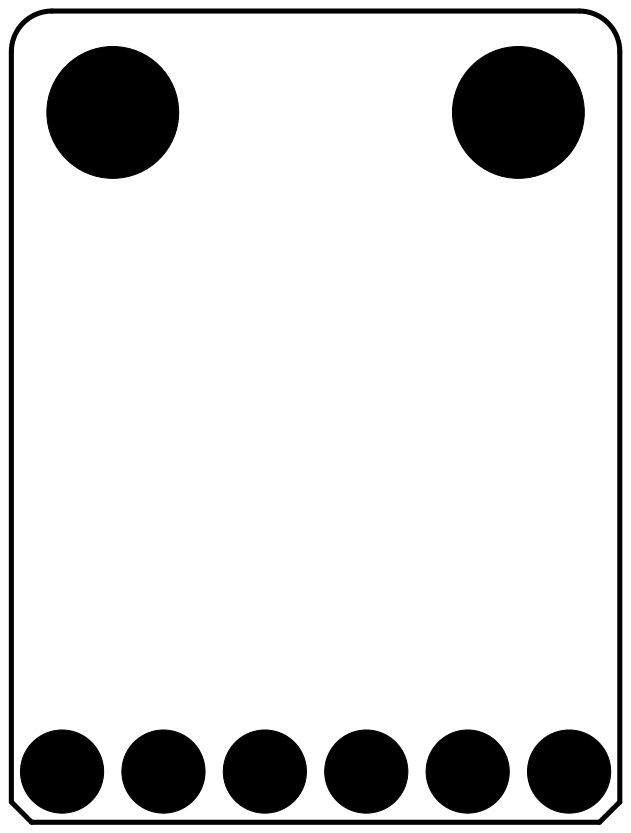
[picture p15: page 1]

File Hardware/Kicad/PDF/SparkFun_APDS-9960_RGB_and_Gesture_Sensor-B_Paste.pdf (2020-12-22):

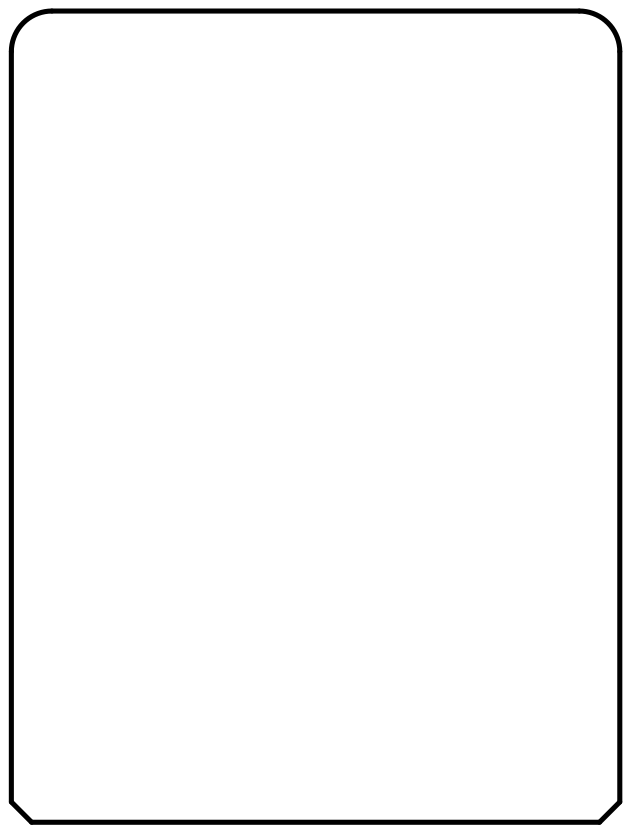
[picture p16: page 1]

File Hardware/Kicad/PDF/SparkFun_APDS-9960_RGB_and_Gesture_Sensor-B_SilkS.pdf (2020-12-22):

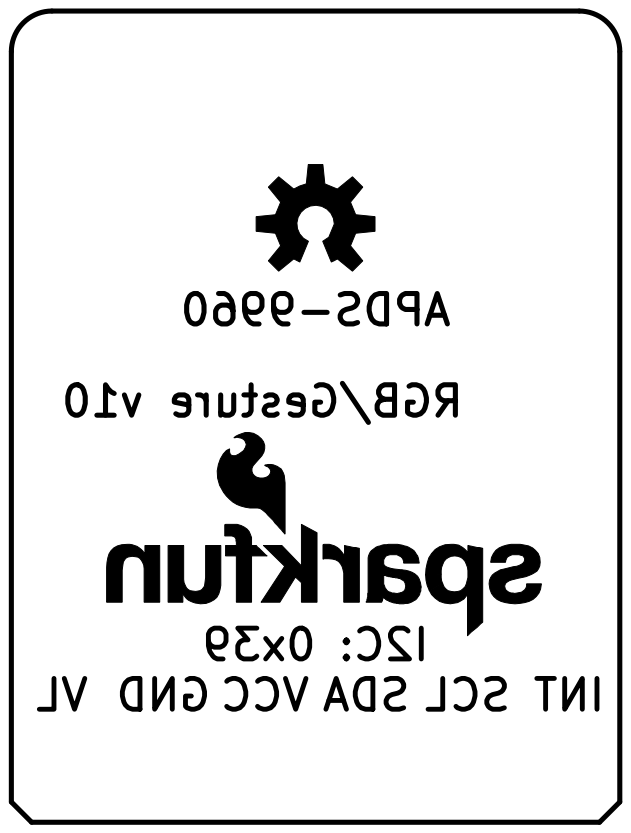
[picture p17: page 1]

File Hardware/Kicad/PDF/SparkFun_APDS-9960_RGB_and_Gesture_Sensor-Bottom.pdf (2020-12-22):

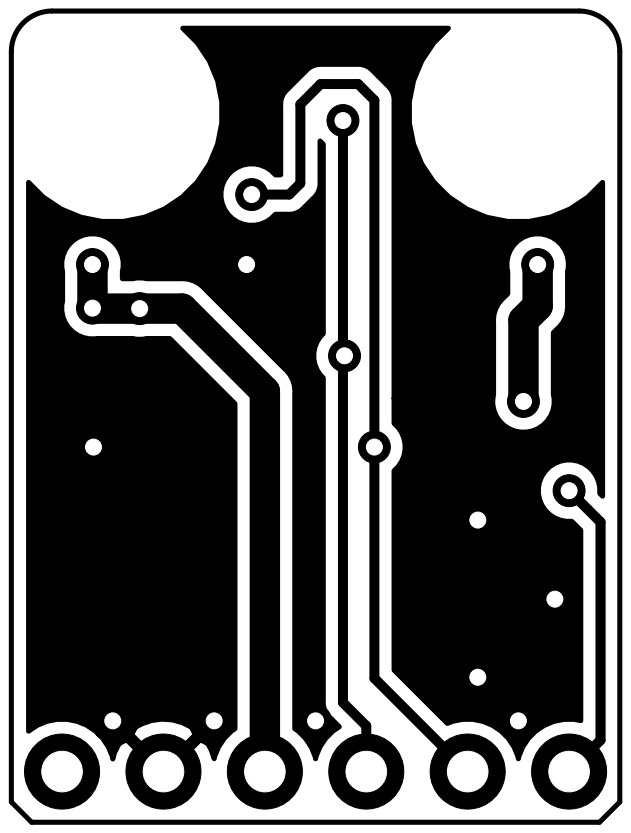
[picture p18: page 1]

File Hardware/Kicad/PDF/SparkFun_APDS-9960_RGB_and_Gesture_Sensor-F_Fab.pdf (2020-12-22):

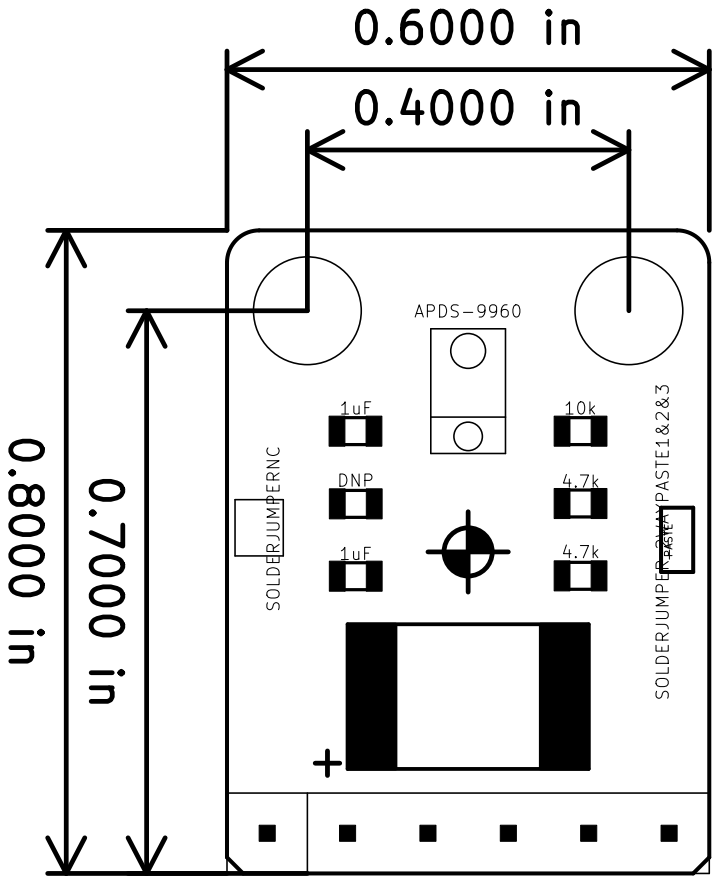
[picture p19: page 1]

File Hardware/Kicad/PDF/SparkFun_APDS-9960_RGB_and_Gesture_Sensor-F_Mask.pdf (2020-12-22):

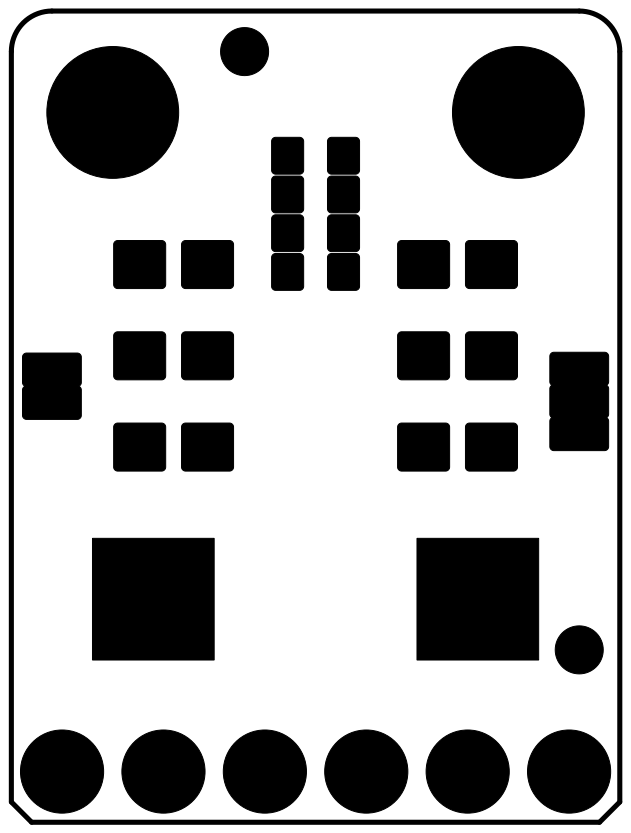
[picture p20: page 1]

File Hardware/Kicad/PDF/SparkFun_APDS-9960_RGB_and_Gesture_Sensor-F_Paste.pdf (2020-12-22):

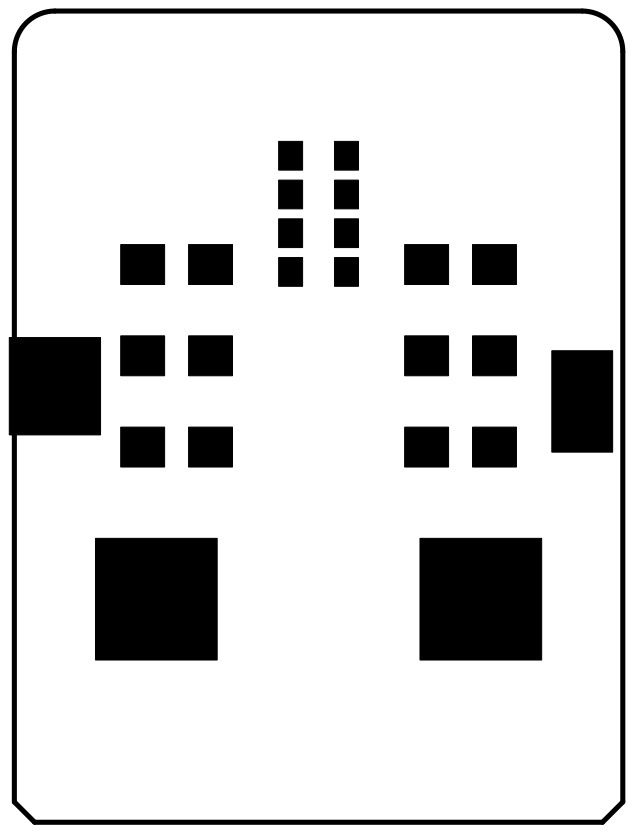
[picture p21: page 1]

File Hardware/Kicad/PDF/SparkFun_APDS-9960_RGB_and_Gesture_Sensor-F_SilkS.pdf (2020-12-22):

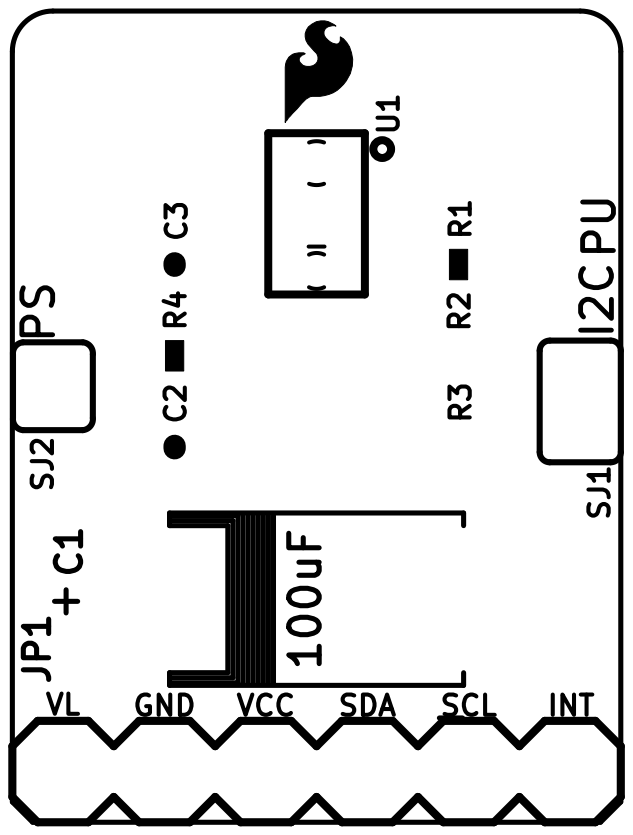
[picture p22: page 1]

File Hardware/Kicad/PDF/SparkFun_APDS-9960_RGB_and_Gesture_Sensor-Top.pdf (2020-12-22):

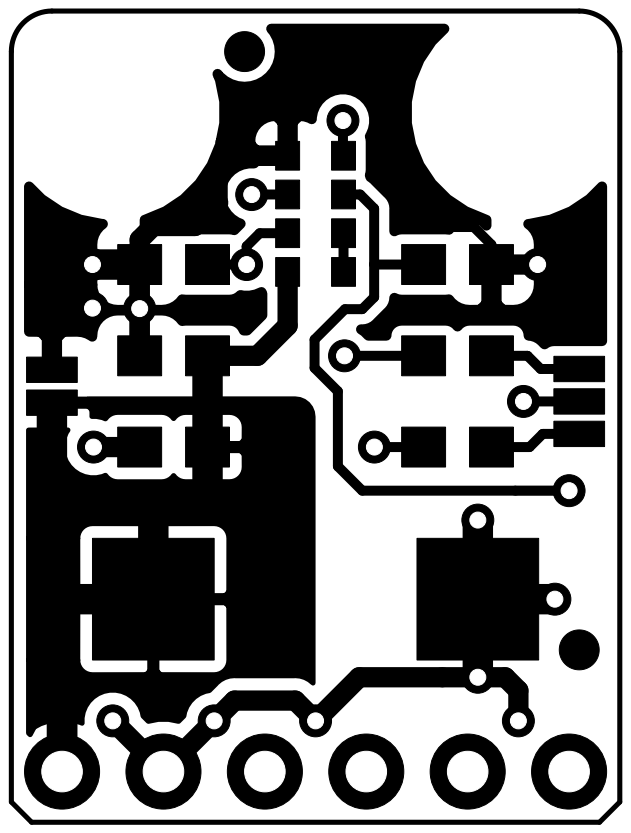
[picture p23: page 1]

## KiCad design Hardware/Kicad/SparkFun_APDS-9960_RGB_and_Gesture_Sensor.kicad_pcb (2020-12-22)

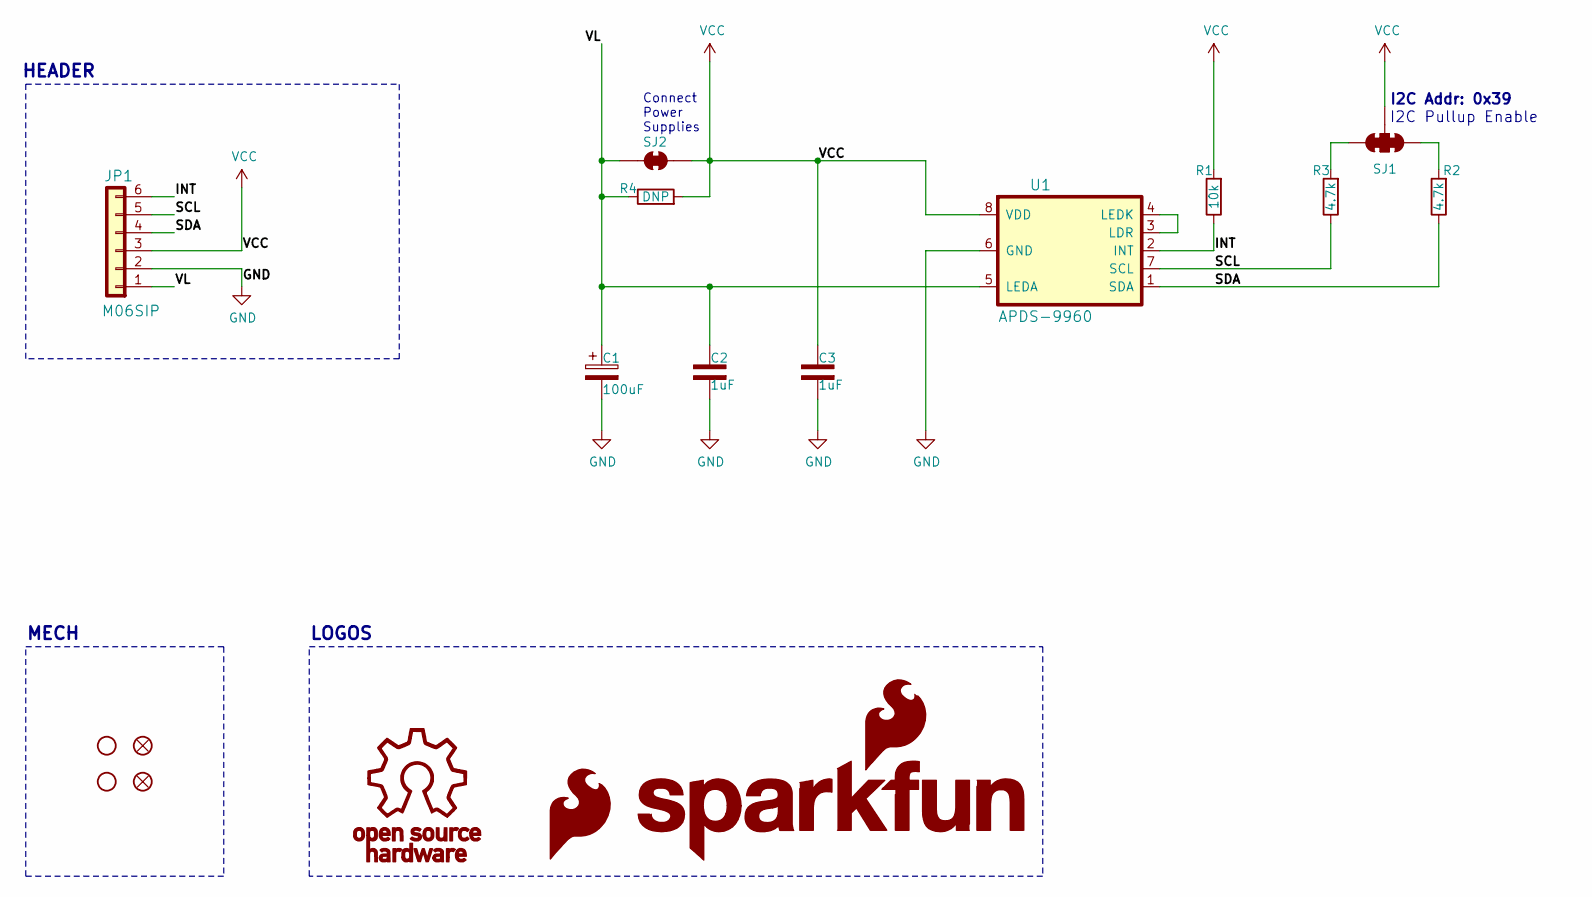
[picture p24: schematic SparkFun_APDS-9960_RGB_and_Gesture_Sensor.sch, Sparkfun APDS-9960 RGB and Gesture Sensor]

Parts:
C1: 100uF; c_2917
C2, C3: 1uF; 0603-CAP
FID1, FID2: FIDUCIAL1X2; FIDUCIAL-1X2
JP1: M06SIP; 1X06
LOGO1: SFE_LOGO_FLAME.1_INCH; SFE_LOGO_NAME_FLAME_.1
LOGO2: OSHW-LOGOS; OSHW-LOGO-S
R1: 10k; 0603-RES
R2, R3: 4.7k; 0603
R4: DNP; 0603-RES
SJ1: SOLDERJUMPER_2WAYPASTE1&2&3; SJ_3_PASTE1&2&3
SJ2: SOLDERJUMPERNC; SJ_2S
STANDOFF1, STANDOFF2: STAND-OFF
U1: APDS-9960
U$1: SFE_LOGO_NAME_FLAME.1_INCH; SFE_LOGO_FLAME_.1

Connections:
/INT: JP1.6, R1.1, U1.2 (INT)
/SCL: JP1.5, R3.1, U1.7 (SCL)
/SDA: JP1.4, R2.1, U1.1 (SDA)
/VL: C1.1, C2.1, JP1.1, R4.1, SJ2.1, U1.5 (LEDA)
GND: C1.2, C2.2, C3.2, JP1.2, U1.6 (GND)
unnamed: R2.2, SJ1.3
unnamed: R3.2, SJ1.1
unnamed: U1.3 (LDR), U1.4 (LEDK)
VCC: C3.1, JP1.3, R1.2, R4.2, SJ1.2, SJ2.2, U1.8 (VDD)

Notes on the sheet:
I2C Addr: 0x39
I2C Pullup Enable
Connect Power Supplies
MECH
LOGOS
HEADER

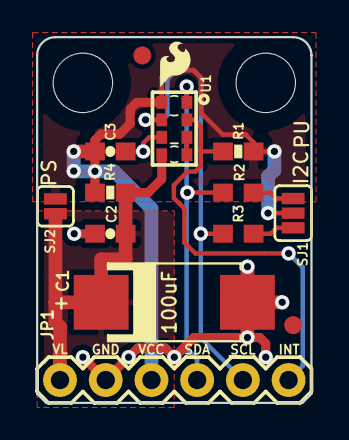
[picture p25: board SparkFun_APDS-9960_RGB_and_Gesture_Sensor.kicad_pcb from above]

Board: 2 copper layers, 15.2 x 20.3 mm, 18 parts (0 on the bottom side), 9 nets.

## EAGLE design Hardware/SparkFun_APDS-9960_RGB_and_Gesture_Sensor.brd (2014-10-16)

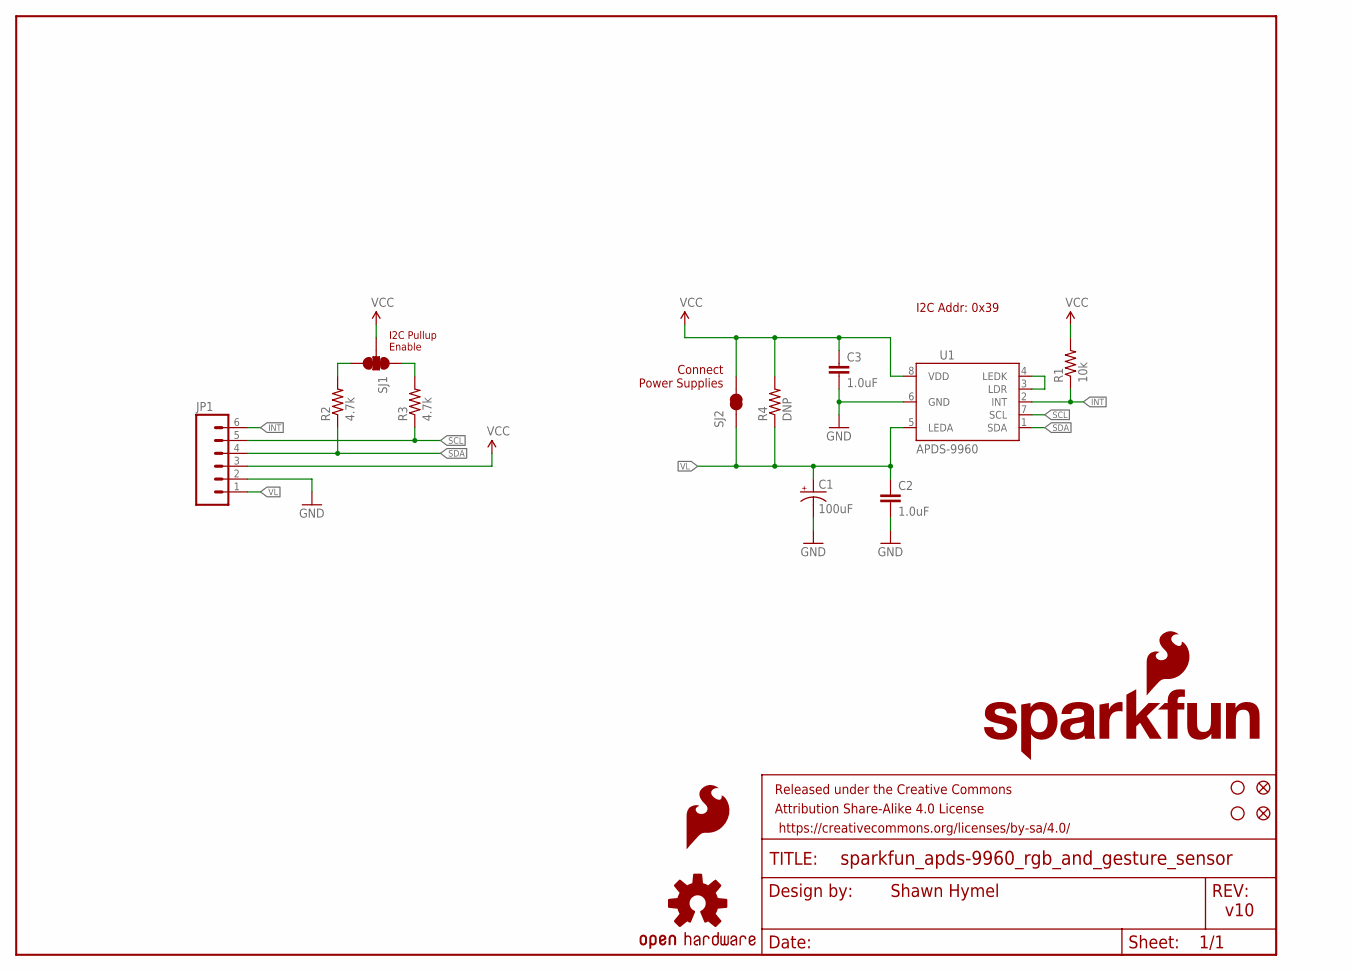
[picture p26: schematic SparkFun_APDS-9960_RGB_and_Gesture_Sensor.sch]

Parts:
C1: 100uF; EIA7343
C2, C3: 1.0uF; 0603-CAP
FID1, FID2: FIDUCIAL1X2; FIDUCIAL-1X2
FRAME1: FRAME-LETTER; CREATIVE_COMMONS
JP1: M06SIP; 1X06
LOGO1: SFE_LOGO_FLAME.1_INCH; SFE_LOGO_FLAME_.1
LOGO2: OSHW-LOGOS; OSHW-LOGO-S
R1: 10k; 0603-RES
R2, R3: 4.7k; 0603
R4: DNP; 0603-RES
SJ1: SOLDERJUMPER_2WAYPASTE1&2&3; SJ_3_PASTE1&2&3
SJ2: SOLDERJUMPERNC; SJ_2S
STANDOFF1, STANDOFF2: STAND-OFF
U1: APDS-9960
U$1: SFE_LOGO_NAME_FLAME.1_INCH; SFE_LOGO_NAME_FLAME_.1

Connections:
GND: C1.C (-), C2.2, C3.2, JP1.2, U1.6 (GND)
INT: JP1.6, R1.1, U1.2 (INT)
unnamed: R2.2, SJ1.3
unnamed: R3.2, SJ1.1
unnamed: U1.3 (LDR), U1.4 (LEDK)
SCL: JP1.5, R3.1, U1.7 (SCL)
SDA: JP1.4, R2.1, U1.1 (SDA)
VCC: C3.1, JP1.3, R1.2, R4.2, SJ1.2, SJ2.2, U1.8 (VDD)
VL: C1.A (+), C2.1, JP1.1, R4.1, SJ2.1, U1.5 (LEDA)

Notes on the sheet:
v10
Shawn Hymel
I2C Addr: 0x39
I2C Pullup Enable
Connect Power Supplies

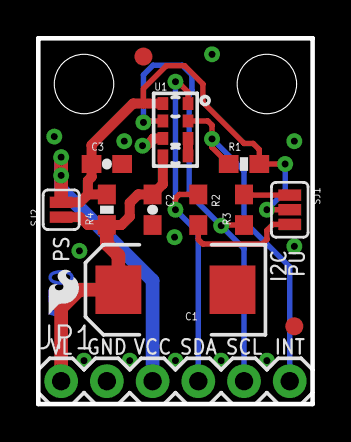
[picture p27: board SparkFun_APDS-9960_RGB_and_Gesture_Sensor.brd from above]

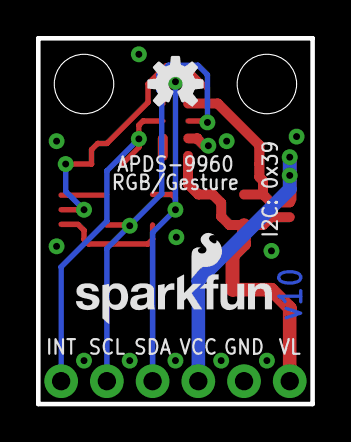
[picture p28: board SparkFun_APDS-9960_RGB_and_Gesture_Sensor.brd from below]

Board: 2 copper layers, 15.2 x 20.3 mm, 19 parts (2 on the bottom side), 9 nets.

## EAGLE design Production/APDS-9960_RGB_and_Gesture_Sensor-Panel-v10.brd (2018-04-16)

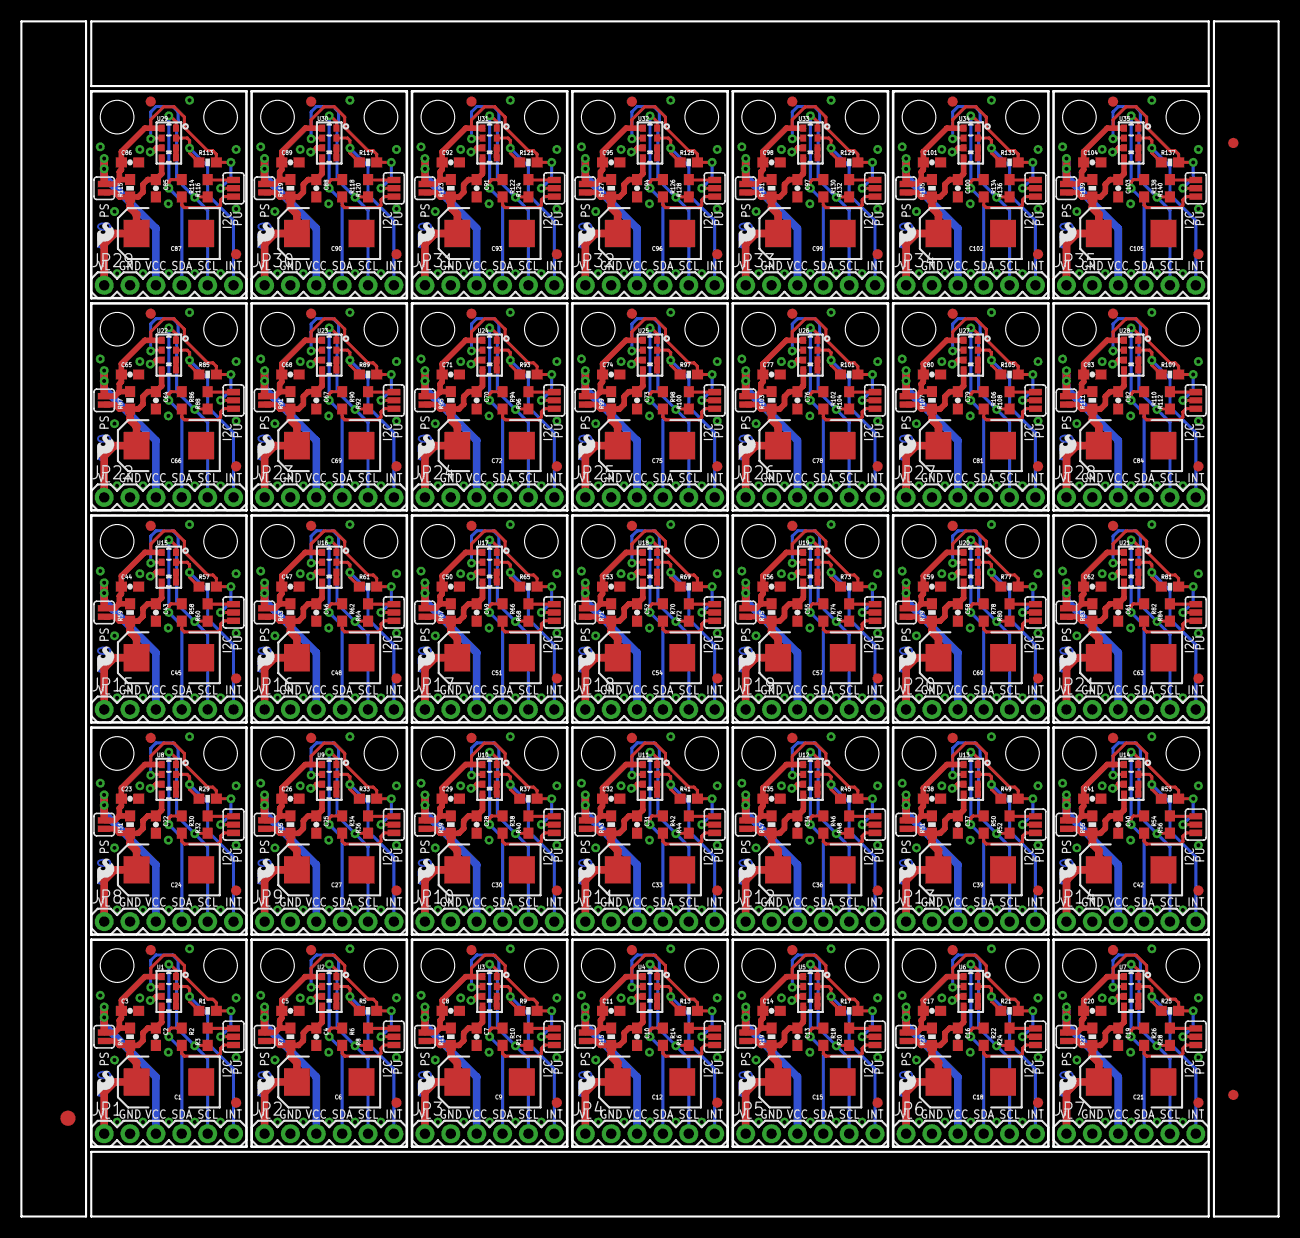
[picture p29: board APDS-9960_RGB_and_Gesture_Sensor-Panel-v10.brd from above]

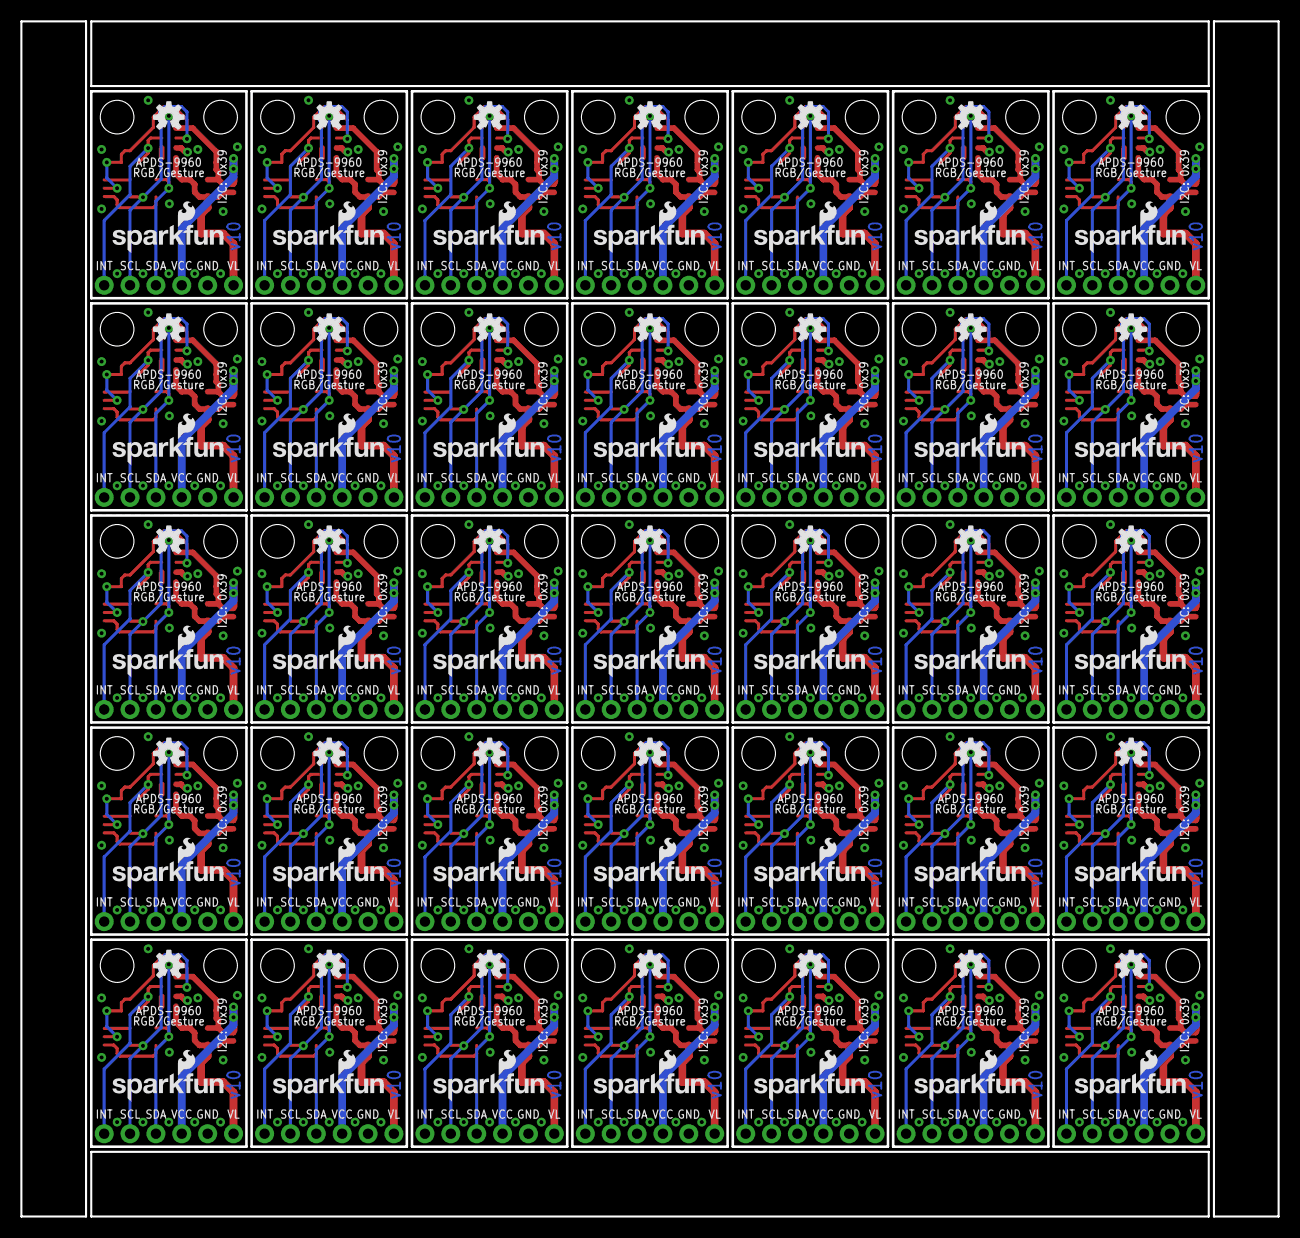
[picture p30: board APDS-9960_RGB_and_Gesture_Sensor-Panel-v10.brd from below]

Board: 2 copper layers, 123.4 x 117.3 mm, 633 parts (70 on the bottom side), 315 nets.

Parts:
C1, C6, C9, C12, C15, C18, C21, C24, C27, C30, C33, C36, C39, C42, C45, C48, C51, C54, C57, C60, C63, C66, C69, C72, C75, C78, C81, C84, C87, C90, C93, C96, C99, C102, C105: 100uF; EIA7343
C2, C3, C4, C5, C7, C8, C10, C11, C13, C14, C16, C17, C19, C20, C22, C23, C25, C26, C28, C29, C31, C32, C34, C35, C37, C38, C40, C41, C43, C44, C46, C47, C49, C50, C52, C53, C55, C56, C58, C59, C61, C62, C64, C65, C67, C68, C70, C71, C73, C74, C76, C77, C79, C80, C82, C83, C85, C86, C88, C89, C91, C92, C94, C95, C97, C98, C100, C101, C103, C104: 1.0uF; 0603-CAP
E$1: FIDUCIAL-1.5X3
E$4, E$6: FIDUCIAL-1X2
FID1, FID2, FID3, FID4, FID5, FID6, FID7, FID8, FID9, FID10, FID11, FID12, FID13, FID14, FID15, FID16, FID17, FID18, FID19, FID20, FID21, FID22, FID23, FID24, FID25, FID26, FID27, FID28, FID29, FID30, FID31, FID32, FID33, FID34, FID35, FID36, FID37, FID38, FID39, FID40, FID41, FID42, FID43, FID44, FID45, FID46, FID47, FID48, FID49, FID50, FID51, FID52, FID53, FID54, FID55, FID56, FID57, FID58, FID59, FID60, FID61, FID62, FID63, FID64, FID65, FID66, FID67, FID68, FID69, FID70: FIDUCIAL1X2; FIDUCIAL-1X2
JP1, JP2, JP3, JP4, JP5, JP6, JP7, JP8, JP9, JP10, JP11, JP12, JP13, JP14, JP15, JP16, JP17, JP18, JP19, JP20, JP21, JP22, JP23, JP24, JP25, JP26, JP27, JP28, JP29, JP30, JP31, JP32, JP33, JP34, JP35: 1X06
LOGO1, LOGO3, LOGO5, LOGO7, LOGO9, LOGO11, LOGO13, LOGO15, LOGO17, LOGO19, LOGO21, LOGO23, LOGO25, LOGO27, LOGO29, LOGO31, LOGO33, LOGO35, LOGO37, LOGO39, LOGO41, LOGO43, LOGO45, LOGO47, LOGO49, LOGO51, LOGO53, LOGO55, LOGO57, LOGO59, LOGO61, LOGO63, LOGO65, LOGO67, LOGO69: SFE_LOGO_FLAME.1_INCH; SFE_LOGO_FLAME_.1
LOGO2, LOGO4, LOGO6, LOGO8, LOGO10, LOGO12, LOGO14, LOGO16, LOGO18, LOGO20, LOGO22, LOGO24, LOGO26, LOGO28, LOGO30, LOGO32, LOGO34, LOGO36, LOGO38, LOGO40, LOGO42, LOGO44, LOGO46, LOGO48, LOGO50, LOGO52, LOGO54, LOGO56, LOGO58, LOGO60, LOGO62, LOGO64, LOGO66, LOGO68, LOGO70: OSHW-LOGOS; OSHW-LOGO-S
R1, R5, R9, R13, R17, R21, R25, R29, R33, R37, R41, R45, R49, R53, R57, R61, R65, R69, R73, R77, R81, R85, R89, R93, R97, R101, R105, R109, R113, R117, R121, R125, R129, R133, R137: 10k; 0603-RES
R2, R3, R6, R8, R10, R12, R14, R16, R18, R20, R22, R24, R26, R28, R30, R32, R34, R36, R38, R40, R42, R44, R46, R48, R50, R52, R54, R56, R58, R60, R62, R64, R66, R68, R70, R72, R74, R76, R78, R80, R82, R84, R86, R88, R90, R92, R94, R96, R98, R100, R102, R104, R106, R108, R110, R112, R114, R116, R118, R120, R122, R124, R126, R128, R130, R132, R134, R136, R138, R140: 4.7k; 0603
R4, R7, R11, R15, R19, R23, R27, R31, R35, R39, R43, R47, R51, R55, R59, R63, R67, R71, R75, R79, R83, R87, R91, R95, R99, R103, R107, R111, R115, R119, R123, R127, R131, R135, R139: DNP; 0603-RES
SJ1, SJ3, SJ5, SJ7, SJ9, SJ11, SJ13, SJ15, SJ17, SJ19, SJ21, SJ23, SJ25, SJ27, SJ29, SJ31, SJ33, SJ35, SJ37, SJ39, SJ41, SJ43, SJ45, SJ47, SJ49, SJ51, SJ53, SJ55, SJ57, SJ59, SJ61, SJ63, SJ65, SJ67, SJ69: SJ_3_PASTE1&2&3
SJ2, SJ4, SJ6, SJ8, SJ10, SJ12, SJ14, SJ16, SJ18, SJ20, SJ22, SJ24, SJ26, SJ28, SJ30, SJ32, SJ34, SJ36, SJ38, SJ40, SJ42, SJ44, SJ46, SJ48, SJ50, SJ52, SJ54, SJ56, SJ58, SJ60, SJ62, SJ64, SJ66, SJ68, SJ70: SOLDERJUMPERNC; SJ_2S
STANDOFF1, STANDOFF2, STANDOFF3, STANDOFF4, STANDOFF5, STANDOFF6, STANDOFF7, STANDOFF8, STANDOFF9, STANDOFF10, STANDOFF11, STANDOFF12, STANDOFF13, STANDOFF14, STANDOFF15, STANDOFF16, STANDOFF17, STANDOFF18, STANDOFF19, STANDOFF20, STANDOFF21, STANDOFF22, STANDOFF23, STANDOFF24, STANDOFF25, STANDOFF26, STANDOFF27, STANDOFF28, STANDOFF29, STANDOFF30, STANDOFF31, STANDOFF32, STANDOFF33, STANDOFF34, STANDOFF35, STANDOFF36, STANDOFF37, STANDOFF38, STANDOFF39, STANDOFF40, STANDOFF41, STANDOFF42, STANDOFF43, STANDOFF44, STANDOFF45, STANDOFF46, STANDOFF47, STANDOFF48, STANDOFF49, STANDOFF50, STANDOFF51, STANDOFF52, STANDOFF53, STANDOFF54, STANDOFF55, STANDOFF56, STANDOFF57, STANDOFF58, STANDOFF59, STANDOFF60, STANDOFF61, STANDOFF62, STANDOFF63, STANDOFF64, STANDOFF65, STANDOFF66, STANDOFF67, STANDOFF68, STANDOFF69, STANDOFF70: STAND-OFF
U1, U2, U3, U4, U5, U6, U7, U8, U9, U10, U11, U12, U13, U14, U15, U16, U17, U18, U19, U20, U21, U22, U23, U24, U25, U26, U27, U28, U29, U30, U31, U32, U33, U34, U35: APDS-9960
U$1, U$2, U$3, U$4, U$5, U$6, U$7, U$8, U$9, U$10, U$11, U$12, U$13, U$14, U$15, U$16, U$17, U$18, U$19, U$20, U$21, U$22, U$23, U$24, U$25, U$26, U$27, U$28, U$29, U$30, U$31, U$32, U$33, U$34, U$35: SFE_LOGO_NAME_FLAME.1_INCH; SFE_LOGO_NAME_FLAME_.1

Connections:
GND: C1.C, C2.2, C3.2, JP1.2, U1.6
GND1: C4.2, C5.2, C6.C, JP2.2, U2.6
GND2: C7.2, C8.2, C9.C, JP3.2, U3.6
GND3: C10.2, C11.2, C12.C, JP4.2, U4.6
GND4: C13.2, C14.2, C15.C, JP5.2, U5.6
GND5: C16.2, C17.2, C18.C, JP6.2, U6.6
GND6: C19.2, C20.2, C21.C, JP7.2, U7.6
GND7: C22.2, C23.2, C24.C, JP8.2, U8.6
GND8: C25.2, C26.2, C27.C, JP9.2, U9.6
GND9: C28.2, C29.2, C30.C, JP10.2, U10.6
GND10: C31.2, C32.2, C33.C, JP11.2, U11.6
GND11: C34.2, C35.2, C36.C, JP12.2, U12.6
GND12: C37.2, C38.2, C39.C, JP13.2, U13.6
GND13: C40.2, C41.2, C42.C, JP14.2, U14.6
GND14: C43.2, C44.2, C45.C, JP15.2, U15.6
GND15: C46.2, C47.2, C48.C, JP16.2, U16.6
GND16: C49.2, C50.2, C51.C, JP17.2, U17.6
GND17: C52.2, C53.2, C54.C, JP18.2, U18.6
GND18: C55.2, C56.2, C57.C, JP19.2, U19.6
GND19: C58.2, C59.2, C60.C, JP20.2, U20.6
GND20: C61.2, C62.2, C63.C, JP21.2, U21.6
GND21: C64.2, C65.2, C66.C, JP22.2, U22.6
GND22: C67.2, C68.2, C69.C, JP23.2, U23.6
GND23: C70.2, C71.2, C72.C, JP24.2, U24.6
GND24: C73.2, C74.2, C75.C, JP25.2, U25.6
GND25: C76.2, C77.2, C78.C, JP26.2, U26.6
GND26: C79.2, C80.2, C81.C, JP27.2, U27.6
GND27: C82.2, C83.2, C84.C, JP28.2, U28.6
GND28: C85.2, C86.2, C87.C, JP29.2, U29.6
GND29: C88.2, C89.2, C90.C, JP30.2, U30.6
GND30: C91.2, C92.2, C93.C, JP31.2, U31.6
GND31: C94.2, C95.2, C96.C, JP32.2, U32.6
GND32: C97.2, C98.2, C99.C, JP33.2, U33.6
GND33: C100.2, C101.2, C102.C, JP34.2, U34.6
GND34: C103.2, C104.2, C105.C, JP35.2, U35.6
INT: JP1.6, R1.1, U1.2
INT1: JP2.6, R5.1, U2.2
INT2: JP3.6, R9.1, U3.2
INT3: JP4.6, R13.1, U4.2
INT4: JP5.6, R17.1, U5.2
INT5: JP6.6, R21.1, U6.2
INT6: JP7.6, R25.1, U7.2
INT7: JP8.6, R29.1, U8.2
INT8: JP9.6, R33.1, U9.2
INT9: JP10.6, R37.1, U10.2
INT10: JP11.6, R41.1, U11.2
INT11: JP12.6, R45.1, U12.2
INT12: JP13.6, R49.1, U13.2
INT13: JP14.6, R53.1, U14.2
INT14: JP15.6, R57.1, U15.2
INT15: JP16.6, R61.1, U16.2
INT16: JP17.6, R65.1, U17.2
INT17: JP18.6, R69.1, U18.2
INT18: JP19.6, R73.1, U19.2
INT19: JP20.6, R77.1, U20.2
INT20: JP21.6, R81.1, U21.2
INT21: JP22.6, R85.1, U22.2
INT22: JP23.6, R89.1, U23.2
INT23: JP24.6, R93.1, U24.2
INT24: JP25.6, R97.1, U25.2
INT25: JP26.6, R101.1, U26.2
INT26: JP27.6, R105.1, U27.2
INT27: JP28.6, R109.1, U28.2
INT28: JP29.6, R113.1, U29.2
INT29: JP30.6, R117.1, U30.2
INT30: JP31.6, R121.1, U31.2
INT31: JP32.6, R125.1, U32.2
INT32: JP33.6, R129.1, U33.2
INT33: JP34.6, R133.1, U34.2
INT34: JP35.6, R137.1, U35.2
unnamed: R2.2, SJ1.3
unnamed: R3.2, SJ1.1
unnamed: U1.3, U1.4
unnamed: R6.2, SJ3.3
unnamed: R8.2, SJ3.1
unnamed: U2.3, U2.4
unnamed: R10.2, SJ5.3
unnamed: R12.2, SJ5.1
unnamed: U3.3, U3.4
unnamed: R14.2, SJ7.3
unnamed: R16.2, SJ7.1
unnamed: U4.3, U4.4
unnamed: R18.2, SJ9.3
unnamed: R20.2, SJ9.1
unnamed: U5.3, U5.4
unnamed: R22.2, SJ11.3
unnamed: R24.2, SJ11.1
unnamed: U6.3, U6.4
unnamed: R26.2, SJ13.3
unnamed: R28.2, SJ13.1
unnamed: U7.3, U7.4
unnamed: R30.2, SJ15.3
unnamed: R32.2, SJ15.1
unnamed: U8.3, U8.4
unnamed: R34.2, SJ17.3
unnamed: R36.2, SJ17.1
unnamed: U9.3, U9.4
unnamed: R38.2, SJ19.3
unnamed: R40.2, SJ19.1
unnamed: U10.3, U10.4
unnamed: R42.2, SJ21.3
unnamed: R44.2, SJ21.1
unnamed: U11.3, U11.4
unnamed: R46.2, SJ23.3
unnamed: R48.2, SJ23.1
unnamed: U12.3, U12.4
unnamed: R50.2, SJ25.3
unnamed: R52.2, SJ25.1
unnamed: U13.3, U13.4
unnamed: R54.2, SJ27.3
unnamed: R56.2, SJ27.1
unnamed: U14.3, U14.4
unnamed: R58.2, SJ29.3
unnamed: R60.2, SJ29.1
unnamed: U15.3, U15.4
unnamed: R62.2, SJ31.3
unnamed: R64.2, SJ31.1
unnamed: U16.3, U16.4
unnamed: R66.2, SJ33.3
unnamed: R68.2, SJ33.1
unnamed: U17.3, U17.4
unnamed: R70.2, SJ35.3
unnamed: R72.2, SJ35.1
unnamed: U18.3, U18.4
unnamed: R74.2, SJ37.3
unnamed: R76.2, SJ37.1
unnamed: U19.3, U19.4
unnamed: R78.2, SJ39.3
unnamed: R80.2, SJ39.1
unnamed: U20.3, U20.4
unnamed: R82.2, SJ41.3
unnamed: R84.2, SJ41.1
unnamed: U21.3, U21.4
unnamed: R86.2, SJ43.3
unnamed: R88.2, SJ43.1
unnamed: U22.3, U22.4
unnamed: R90.2, SJ45.3
unnamed: R92.2, SJ45.1
unnamed: U23.3, U23.4
unnamed: R94.2, SJ47.3
unnamed: R96.2, SJ47.1
unnamed: U24.3, U24.4
unnamed: R98.2, SJ49.3
unnamed: R100.2, SJ49.1
unnamed: U25.3, U25.4
unnamed: R102.2, SJ51.3
unnamed: R104.2, SJ51.1
unnamed: U26.3, U26.4
unnamed: R106.2, SJ53.3
unnamed: R108.2, SJ53.1
unnamed: U27.3, U27.4
unnamed: R110.2, SJ55.3
unnamed: R112.2, SJ55.1
unnamed: U28.3, U28.4
unnamed: R114.2, SJ57.3
unnamed: R116.2, SJ57.1
unnamed: U29.3, U29.4
unnamed: R118.2, SJ59.3
unnamed: R120.2, SJ59.1
unnamed: U30.3, U30.4
unnamed: R122.2, SJ61.3
unnamed: R124.2, SJ61.1
unnamed: U31.3, U31.4
unnamed: R126.2, SJ63.3
unnamed: R128.2, SJ63.1
unnamed: U32.3, U32.4
unnamed: R130.2, SJ65.3
unnamed: R132.2, SJ65.1
unnamed: U33.3, U33.4
unnamed: R134.2, SJ67.3
unnamed: R136.2, SJ67.1
unnamed: U34.3, U34.4
unnamed: R138.2, SJ69.3
unnamed: R140.2, SJ69.1
unnamed: U35.3, U35.4
SCL: JP1.5, R3.1, U1.7
SCL1: JP2.5, R8.1, U2.7
SCL2: JP3.5, R12.1, U3.7
SCL3: JP4.5, R16.1, U4.7
SCL4: JP5.5, R20.1, U5.7
SCL5: JP6.5, R24.1, U6.7
SCL6: JP7.5, R28.1, U7.7
SCL7: JP8.5, R32.1, U8.7
SCL8: JP9.5, R36.1, U9.7
SCL9: JP10.5, R40.1, U10.7
SCL10: JP11.5, R44.1, U11.7
SCL11: JP12.5, R48.1, U12.7
SCL12: JP13.5, R52.1, U13.7
SCL13: JP14.5, R56.1, U14.7
SCL14: JP15.5, R60.1, U15.7
SCL15: JP16.5, R64.1, U16.7
SCL16: JP17.5, R68.1, U17.7
SCL17: JP18.5, R72.1, U18.7
SCL18: JP19.5, R76.1, U19.7
SCL19: JP20.5, R80.1, U20.7
SCL20: JP21.5, R84.1, U21.7
SCL21: JP22.5, R88.1, U22.7
SCL22: JP23.5, R92.1, U23.7
SCL23: JP24.5, R96.1, U24.7
SCL24: JP25.5, R100.1, U25.7
SCL25: JP26.5, R104.1, U26.7
SCL26: JP27.5, R108.1, U27.7
SCL27: JP28.5, R112.1, U28.7
SCL28: JP29.5, R116.1, U29.7
SCL29: JP30.5, R120.1, U30.7
SCL30: JP31.5, R124.1, U31.7
SCL31: JP32.5, R128.1, U32.7
SCL32: JP33.5, R132.1, U33.7
SCL33: JP34.5, R136.1, U34.7
SCL34: JP35.5, R140.1, U35.7
SDA: JP1.4, R2.1, U1.1
SDA1: JP2.4, R6.1, U2.1
SDA2: JP3.4, R10.1, U3.1
SDA3: JP4.4, R14.1, U4.1
SDA4: JP5.4, R18.1, U5.1
SDA5: JP6.4, R22.1, U6.1
SDA6: JP7.4, R26.1, U7.1
SDA7: JP8.4, R30.1, U8.1
SDA8: JP9.4, R34.1, U9.1
SDA9: JP10.4, R38.1, U10.1
SDA10: JP11.4, R42.1, U11.1
SDA11: JP12.4, R46.1, U12.1
SDA12: JP13.4, R50.1, U13.1
SDA13: JP14.4, R54.1, U14.1
SDA14: JP15.4, R58.1, U15.1
SDA15: JP16.4, R62.1, U16.1
SDA16: JP17.4, R66.1, U17.1
SDA17: JP18.4, R70.1, U18.1
SDA18: JP19.4, R74.1, U19.1
SDA19: JP20.4, R78.1, U20.1
SDA20: JP21.4, R82.1, U21.1
SDA21: JP22.4, R86.1, U22.1
SDA22: JP23.4, R90.1, U23.1
SDA23: JP24.4, R94.1, U24.1
SDA24: JP25.4, R98.1, U25.1
SDA25: JP26.4, R102.1, U26.1
SDA26: JP27.4, R106.1, U27.1
SDA27: JP28.4, R110.1, U28.1
SDA28: JP29.4, R114.1, U29.1
SDA29: JP30.4, R118.1, U30.1
SDA30: JP31.4, R122.1, U31.1
SDA31: JP32.4, R126.1, U32.1
SDA32: JP33.4, R130.1, U33.1
SDA33: JP34.4, R134.1, U34.1
SDA34: JP35.4, R138.1, U35.1
VCC: C3.1, JP1.3, R1.2, R4.2, SJ1.2, SJ2.2, U1.8
VCC1: C5.1, JP2.3, R5.2, R7.2, SJ3.2, SJ4.2, U2.8
VCC2: C8.1, JP3.3, R9.2, R11.2, SJ5.2, SJ6.2, U3.8
VCC3: C11.1, JP4.3, R13.2, R15.2, SJ7.2, SJ8.2, U4.8
VCC4: C14.1, JP5.3, R17.2, R19.2, SJ9.2, SJ10.2, U5.8
VCC5: C17.1, JP6.3, R21.2, R23.2, SJ11.2, SJ12.2, U6.8
VCC6: C20.1, JP7.3, R25.2, R27.2, SJ13.2, SJ14.2, U7.8
VCC7: C23.1, JP8.3, R29.2, R31.2, SJ15.2, SJ16.2, U8.8
VCC8: C26.1, JP9.3, R33.2, R35.2, SJ17.2, SJ18.2, U9.8
VCC9: C29.1, JP10.3, R37.2, R39.2, SJ19.2, SJ20.2, U10.8
VCC10: C32.1, JP11.3, R41.2, R43.2, SJ21.2, SJ22.2, U11.8
VCC11: C35.1, JP12.3, R45.2, R47.2, SJ23.2, SJ24.2, U12.8
VCC12: C38.1, JP13.3, R49.2, R51.2, SJ25.2, SJ26.2, U13.8
VCC13: C41.1, JP14.3, R53.2, R55.2, SJ27.2, SJ28.2, U14.8
VCC14: C44.1, JP15.3, R57.2, R59.2, SJ29.2, SJ30.2, U15.8
VCC15: C47.1, JP16.3, R61.2, R63.2, SJ31.2, SJ32.2, U16.8
VCC16: C50.1, JP17.3, R65.2, R67.2, SJ33.2, SJ34.2, U17.8
VCC17: C53.1, JP18.3, R69.2, R71.2, SJ35.2, SJ36.2, U18.8
VCC18: C56.1, JP19.3, R73.2, R75.2, SJ37.2, SJ38.2, U19.8
VCC19: C59.1, JP20.3, R77.2, R79.2, SJ39.2, SJ40.2, U20.8
VCC20: C62.1, JP21.3, R81.2, R83.2, SJ41.2, SJ42.2, U21.8
VCC21: C65.1, JP22.3, R85.2, R87.2, SJ43.2, SJ44.2, U22.8
VCC22: C68.1, JP23.3, R89.2, R91.2, SJ45.2, SJ46.2, U23.8
VCC23: C71.1, JP24.3, R93.2, R95.2, SJ47.2, SJ48.2, U24.8
VCC24: C74.1, JP25.3, R97.2, R99.2, SJ49.2, SJ50.2, U25.8
VCC25: C77.1, JP26.3, R101.2, R103.2, SJ51.2, SJ52.2, U26.8
VCC26: C80.1, JP27.3, R105.2, R107.2, SJ53.2, SJ54.2, U27.8
VCC27: C83.1, JP28.3, R109.2, R111.2, SJ55.2, SJ56.2, U28.8
VCC28: C86.1, JP29.3, R113.2, R115.2, SJ57.2, SJ58.2, U29.8
VCC29: C89.1, JP30.3, R117.2, R119.2, SJ59.2, SJ60.2, U30.8
VCC30: C92.1, JP31.3, R121.2, R123.2, SJ61.2, SJ62.2, U31.8
VCC31: C95.1, JP32.3, R125.2, R127.2, SJ63.2, SJ64.2, U32.8
VCC32: C98.1, JP33.3, R129.2, R131.2, SJ65.2, SJ66.2, U33.8
VCC33: C101.1, JP34.3, R133.2, R135.2, SJ67.2, SJ68.2, U34.8
VCC34: C104.1, JP35.3, R137.2, R139.2, SJ69.2, SJ70.2, U35.8
VL: C1.A, C2.1, JP1.1, R4.1, SJ2.1, U1.5
VL1: C4.1, C6.A, JP2.1, R7.1, SJ4.1, U2.5
VL2: C7.1, C9.A, JP3.1, R11.1, SJ6.1, U3.5
VL3: C10.1, C12.A, JP4.1, R15.1, SJ8.1, U4.5
VL4: C13.1, C15.A, JP5.1, R19.1, SJ10.1, U5.5
VL5: C16.1, C18.A, JP6.1, R23.1, SJ12.1, U6.5
VL6: C19.1, C21.A, JP7.1, R27.1, SJ14.1, U7.5
VL7: C22.1, C24.A, JP8.1, R31.1, SJ16.1, U8.5
VL8: C25.1, C27.A, JP9.1, R35.1, SJ18.1, U9.5
VL9: C28.1, C30.A, JP10.1, R39.1, SJ20.1, U10.5
VL10: C31.1, C33.A, JP11.1, R43.1, SJ22.1, U11.5
VL11: C34.1, C36.A, JP12.1, R47.1, SJ24.1, U12.5
VL12: C37.1, C39.A, JP13.1, R51.1, SJ26.1, U13.5
VL13: C40.1, C42.A, JP14.1, R55.1, SJ28.1, U14.5
VL14: C43.1, C45.A, JP15.1, R59.1, SJ30.1, U15.5
VL15: C46.1, C48.A, JP16.1, R63.1, SJ32.1, U16.5
VL16: C49.1, C51.A, JP17.1, R67.1, SJ34.1, U17.5
VL17: C52.1, C54.A, JP18.1, R71.1, SJ36.1, U18.5
VL18: C55.1, C57.A, JP19.1, R75.1, SJ38.1, U19.5
VL19: C58.1, C60.A, JP20.1, R79.1, SJ40.1, U20.5
VL20: C61.1, C63.A, JP21.1, R83.1, SJ42.1, U21.5
VL21: C64.1, C66.A, JP22.1, R87.1, SJ44.1, U22.5
VL22: C67.1, C69.A, JP23.1, R91.1, SJ46.1, U23.5
VL23: C70.1, C72.A, JP24.1, R95.1, SJ48.1, U24.5
VL24: C73.1, C75.A, JP25.1, R99.1, SJ50.1, U25.5
VL25: C76.1, C78.A, JP26.1, R103.1, SJ52.1, U26.5
VL26: C79.1, C81.A, JP27.1, R107.1, SJ54.1, U27.5
VL27: C82.1, C84.A, JP28.1, R111.1, SJ56.1, U28.5
VL28: C85.1, C87.A, JP29.1, R115.1, SJ58.1, U29.5
VL29: C88.1, C90.A, JP30.1, R119.1, SJ60.1, U30.5
VL30: C91.1, C93.A, JP31.1, R123.1, SJ62.1, U31.5
VL31: C94.1, C96.A, JP32.1, R127.1, SJ64.1, U32.5
VL32: C97.1, C99.A, JP33.1, R131.1, SJ66.1, U33.5
VL33: C100.1, C102.A, JP34.1, R135.1, SJ68.1, U34.5
VL34: C103.1, C105.A, JP35.1, R139.1, SJ70.1, U35.5

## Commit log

2014-03-03 Created schematic for breakout board
    [APDS-9960_RGB_and_Gesture_Sensor.brd, APDS-9960_RGB_and_Gesture_Sensor.sch]
2014-03-05 Created initial layout
    [APDS-9960_RGB_and_Gesture_Sensor.brd, APDS-9960_RGB_and_Gesture_Sensor.sch]
2014-03-05 Added SS text
    [APDS-9960_RGB_and_Gesture_Sensor.brd, APDS-9960_RGB_and_Gesture_Sensor.sch]
2014-03-05 Added name on layout
    [APDS-9960_RGB_and_Gesture_Sensor.brd]
2014-03-05 Replaced 4.7k INT pullup with 10k
    [APDS-9960_RGB_and_Gesture_Sensor.brd, APDS-9960_RGB_and_Gesture_Sensor.sch]
2014-03-12 Rotated OSHW logo and added I2C address to sch and silk.
    [APDS-9960_RGB_and_Gesture_Sensor.brd, APDS-9960_RGB_and_Gesture_Sensor.sch]
2014-05-14 Added separate VLED (VL) pin, connected VL and VCC with solder jumper and optional resistor. Re-did layout to support new features.
    [APDS-9960_RGB_and_Gesture_Sensor.brd, APDS-9960_RGB_and_Gesture_Sensor.sch]
2014-05-14 Fixed text font and size on schematic
    [APDS-9960_RGB_and_Gesture_Sensor.sch]
2014-06-09 Added led gain control and photodiode mask methods
2014-07-15 Updated version number to v10 for reds
    [APDS-9960_RGB_and_Gesture_Sensor.brd, APDS-9960_RGB_and_Gesture_Sensor.sch]
2014-07-15 created panel v10
    [APDS-9960_RGB_and_Gesture_Sensor-Panel-v10.brd]
2014-10-23 Moved several get/set methods to public. Added power on/off method.
2014-10-24 Added methods to control light sensor and light sensor demo sketch.
2014-10-27 Added methods for controlling ambient light interrupt thresholds.
2014-10-28 Finished interrupt demos for the library.
2014-11-03 Added PDF of schematic
2014-11-05 Changed the names of files and Arduino libraries to contain 'SparkFun_' as a prefix
    [SparkFun_APDS-9960_RGB_and_Gesture_Sensor.brd, SparkFun_APDS-9960_RGB_and_Gesture_Sensor.sch]
2014-11-18 Added pinMode like to GestureTest.ino example to fix interrupt not working with some Arduinos.
2015-02-04 Changed 4.7k resistors to proper 0603-RES package.
    This adds a small silkscreen dot under the resistor.
    [SparkFun_APDS-9960_RGB_and_Gesture_Sensor.brd, SparkFun_APDS-9960_RGB_and_Gesture_Sensor.sch]
2015-02-05 Reverting to current board layout files
    [SparkFun_APDS-9960_RGB_and_Gesture_Sensor.brd, SparkFun_APDS-9960_RGB_and_Gesture_Sensor.sch]
2015-04-26 Squashed 'Libraries/Arduino/' content from commit cb761c9
    git-subtree-dir: Libraries/Arduino
    git-subtree-split: cb761c9f0f9f36acc54a8502904df46fbca3fc06
2015-04-26 Updated to new library structure
    [APDS-9960_RGB_and_Gesture_Sensor-Panel-v10.brd]
2015-04-29 Part of the new arduino lib format updates
2015-04-29 Squashed 'Libraries/Arduino/' content from commit d35b342
    git-subtree-split: d35b342f01b4587b4a9401d6ab1262f9d95b321b
    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
2015-05-13 Squashed 'Libraries/Arduino/' changes from d35b342..e60af2c
    git-subtree-split: e60af2cdf0042a4ac6cdcac1a4fe5b38b0d575b7
    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
2015-07-21 Squashed 'Libraries/Arduino/' changes from e60af2c..347a7d5
    347a7d5 Updating library name
    git-subtree-split: 347a7d55f1cf009bff58c28733b1f0bd2172092e
    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
2017-07-10 Put Arduino library in its own folder
    The previous folder structure did not match the installation instructions found in the library's README.md file. The previous library folder name "Arduino" was very unhelpful.
2018-04-16 new panel
    [APDS-9960_RGB_and_Gesture_Sensor-Panel-v10.brd]
2019-06-08 Add GY-9960LLC APDS-9960 sensor support
2020-06-04 fixing issue with Wire usage, finicky compilers throwing warnings, issue where gesture recognition fails if one diode pair is activated, issue where gesture recognition sometimes crashed esp based sy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
2020-12-22 Adding WyoLum's Kicad version.
    [APDS-9960--3DModel-STEP-56544.step, APDS_9970_cp.step, C_0603_1608Metric.step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]

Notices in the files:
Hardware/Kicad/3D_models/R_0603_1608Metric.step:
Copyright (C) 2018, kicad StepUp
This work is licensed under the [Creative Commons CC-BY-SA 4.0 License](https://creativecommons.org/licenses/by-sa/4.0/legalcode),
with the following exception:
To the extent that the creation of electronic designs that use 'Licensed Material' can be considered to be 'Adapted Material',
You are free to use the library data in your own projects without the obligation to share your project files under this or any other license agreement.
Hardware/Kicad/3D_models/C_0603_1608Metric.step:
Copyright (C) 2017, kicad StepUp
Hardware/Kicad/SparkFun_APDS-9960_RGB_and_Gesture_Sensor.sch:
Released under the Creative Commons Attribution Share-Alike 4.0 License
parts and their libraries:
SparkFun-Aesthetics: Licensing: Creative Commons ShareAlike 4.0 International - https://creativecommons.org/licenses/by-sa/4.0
